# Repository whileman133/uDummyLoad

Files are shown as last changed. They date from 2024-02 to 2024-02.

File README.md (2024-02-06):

# 20W/50Ω μDummy RF Load with Wattmeter

This is the home of the design files and firmware for the μDummy RF Load project. See the description of the unit and the resources in this repo below.

## Description

This micro-size 50Ω RF dummy load with built-in wattmeter is well-suited for testing portable rigs. 
The glass LCD provides time-average power readings between 0.15 and 20W with 0.1W precision. 
Batteries are not required, as the unit draws power from the RF source, consuming a maximum of 3.0mA at the full rated input power. 
The board itself serves as a heatsink provided the operator limits the duration of the RF input. 
Improve the accuracy by loading a calibration table of up to 60 rows into EEPROM using an Arduino microcontroller.

## Organization of this Repo

- `2_Documentation/`: datasheet and documentation for the μDummy load unit
- `3_Mechanical/`: mechanical design files (primarily thermal analysis)
- `3_Electrical/`: KiCAD design files and LTspice simulation files
- `4_Software/`: firmware files
  - `uDummyLoad_PIC18F24Q10.X/`: firmware for the PIC microcontroller
  - `uDummyLoad_TranslatorArduino/`: Arduino sketch for uploading calibration table to the unit with an Arduino microcontroller

 ## License

Apache License, Version 2.0. See `LICENSE`.

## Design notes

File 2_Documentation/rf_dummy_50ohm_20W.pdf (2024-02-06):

## 20W/50Ω µDummy Load with Wattmeter

ASMV Electrical

Last Updated: February 6, 2024

Difficulty of Assembly: 3 out of 10 – Through-Hole Parts Only –

1

### Contents

2

RF-331: 20W Dummy Load | ASMV Electrical

### 1 Overview

This micro-size 50Ω RF dummy load with built-in wattmeter is well-suited for testing portable rigs. The glass LCD provides time-average power readings between 0.15 and 20W with 0.1W precision. Batteries are not required, as the unit draws power from the RF source, consuming a maximum of 3.0mA at the full rated input power. The board itself serves as a heatsink provided the operator limits the duration of the RF input. Improve the accuracy by loading a calibration table of up to 60 rows into EEPROM using an Arduino microcontroller.

Table 1: Characteristics

Parameter | Conditions Min. Typ. Max. Unit
Input power | 0.15¹

### 20 W

Peak ac input voltage | 3.9 | 45 | V
Wattmeter op. frequency | dc²

### 50 MHz

Dummy load op. frequency | dc | 150 | MHz
Uncalibrated error
(fin ≤ 10 MHz)
Pin = 1.0W | 0.1 | 0.2 | W
Pin = 20W | 0.7 | 1.3 | W
Uncalibrated error
(fin = 50 MHz)
Pin = 1.0W | 0.2 | 0.3 | W
Pin = 20W | 1.0 | 2.0 | W

Safe operating time
(TA = 25℃)
Pin = 10W | | 24 | sec
Pin = 15W | | 11 | sec
Pin = 20W | | 5 | sec
80% cool-down time³

### 3.5 min

3

RF-331: 20W Dummy Load | ASMV Electrical

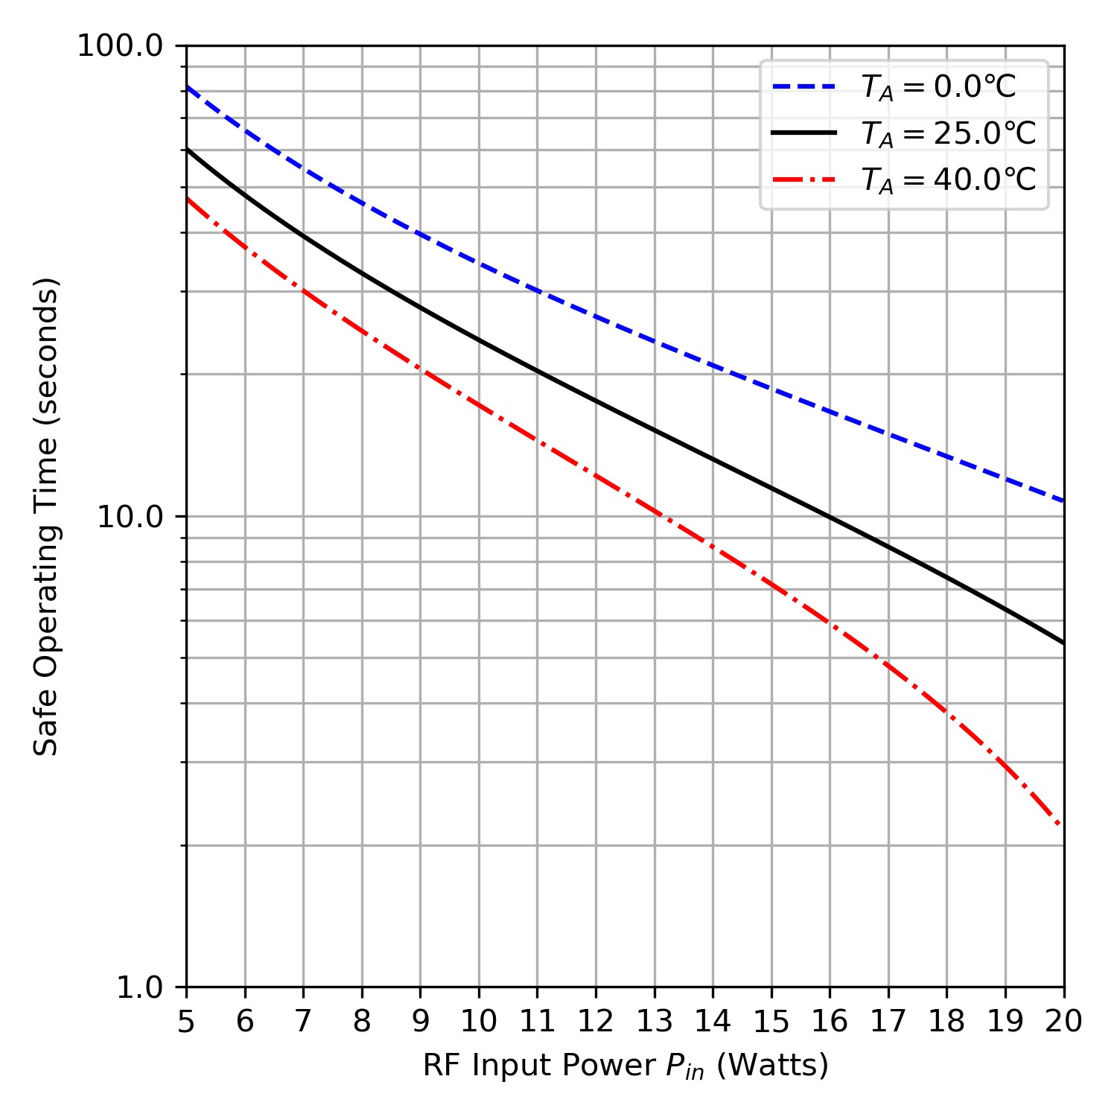
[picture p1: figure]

Figure 1: Safe Operating Time versus Input Power and Ambient Temperature

1The wattmeter will not operate when the input power falls below the rated minimum.
2To obtain the correct power at dc, double the meter reading.
3This is the cool-off time observed indoors with minimal air flow.

4

RF-331: 20W Dummy Load | ASMV Electrical

### 2 Assembly Instructions

Before proceeding, make sure that you have the parts in listed on this page and pictured on the next page. The board comes pre-populated with the surface-mount components. To complete the assembly, solder the remaining through-hole components to the board by following the steps on page 7. When complete, your board should look like the picture on on page 8. For best results, use rosin-core 63/37 PbSn solder, the eutectic alloy that melts at 181℃/361°F.

Parts List

Table 2: Kit Parts List

Qty. Reference(s) Description | Package Marking
1 | PCB | µDummy Load PCB | RF-331 Rev. 2
3 | D1, D2, D3 BAT46 Schottky diode | BAT46
2 | C1, C3 | 5.6nF peak-detector caps | 562
2 | C2, C4 | 1µF 100V decoupling caps | 105K
1 | C5 | 10nF decoupling cap | 103
1 | R3 | 100kΩ 0.1% precision resistor BrownBlackBlackOrangeViolet
1 | R4 | 10kΩ 0.1% precision resistor | BrownBlackBlackRedViolet
1 | R5 | 100kΩ 5% diode resistor | BrownBlackYellowGold
1 | R6 | 2.4kΩ 5%Vref resistor | RedYellowRedGold
1 | J1 | Male BNC 50Ω PCB-mount | —
1 | U4 | 24-pin reflective LCD | —

5

RF-331: 20W Dummy Load | ASMV Electrical

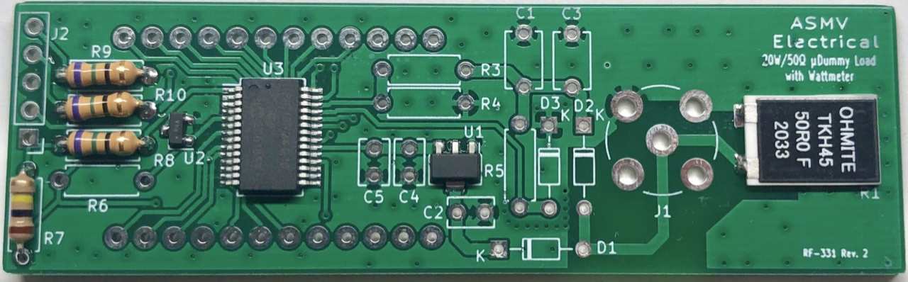
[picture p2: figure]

(a) PCB Front

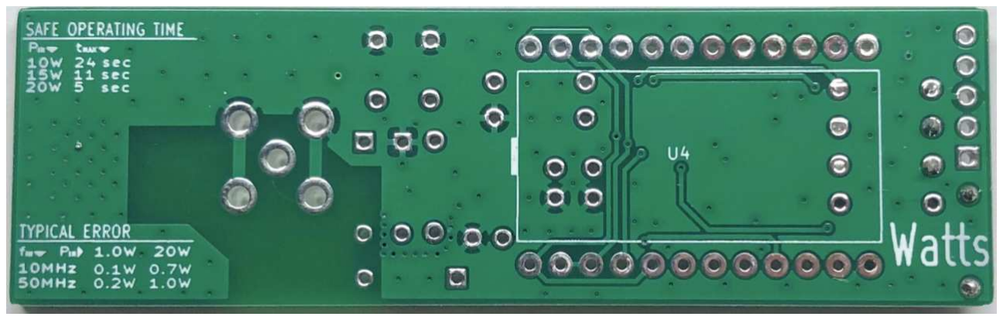
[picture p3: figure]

(b) PCB Back

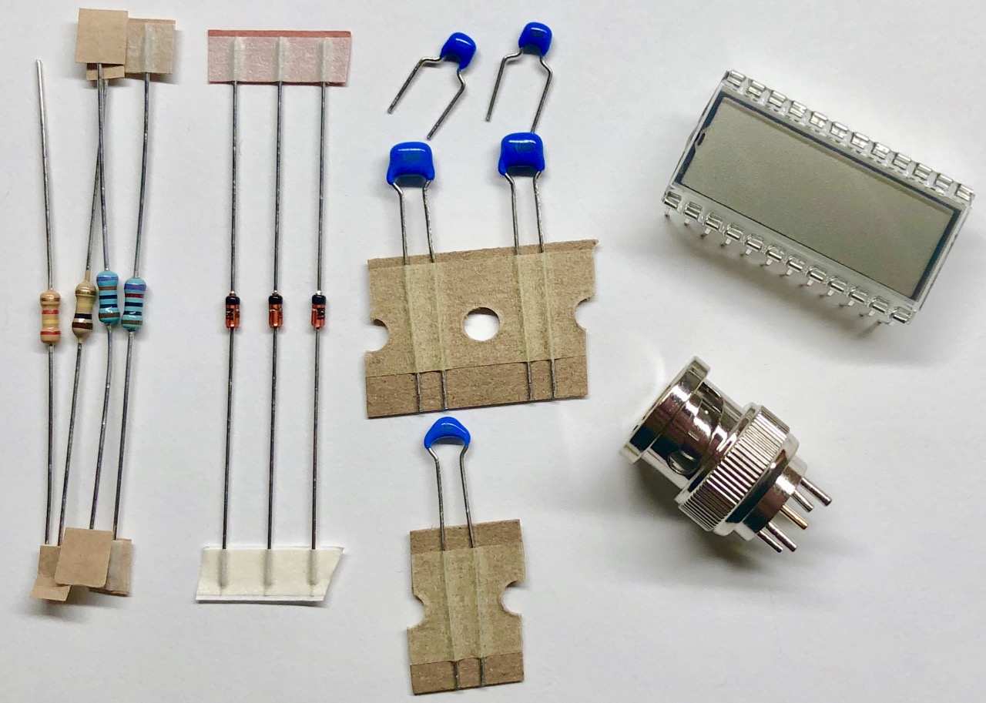
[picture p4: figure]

(c) Parts
Figure 2: Kit before assembly.

6

RF-331: 20W Dummy Load | ASMV Electrical

Assembly Steps

### 1. Place and solder the Schottky diodes D1, D2, D3 onto the board. Make

sure to orient the diodes so that the cathode band is closer to the pad marked “K”.

### 2. Place and solder the peak-detector capacitors C1, C3, the rectifier ca-

pacitor C2, and the diode biasing resistor R5 onto the board.

3. Place but do not solder the precision voltage divider resistors R3, R4, the decoupling capacitors C4, C5, and the voltage reference biasing resistor R6 onto the board.

### 4. Turn the board over and cut leads that protrude out of the LCD area

(U4) flush with the board. If necessary, remove the parts to cut the
leads. Rough or jagged pieces of metal extending out from the board may damage the LCD.
5. Solder the previously-placed parts R3, R4, C4, C5, R6 to the board.

### 6. Turn the board over and insert the 24-pin LCD (U4). Make sure to orient

the LCD so that the edge with the raised notch aligns with the mark on the silkscreen. Turn over the board and solder the LCD in place.

### 7. Place and solder the BNC connector J1 onto the board. Apply a rosin

flux to outer shield pins before soldering. These pins may require additional heat to form a good joint.

8. Remove the protective film from the LCD.

7

RF-331: 20W Dummy Load | ASMV Electrical

Assembled Board

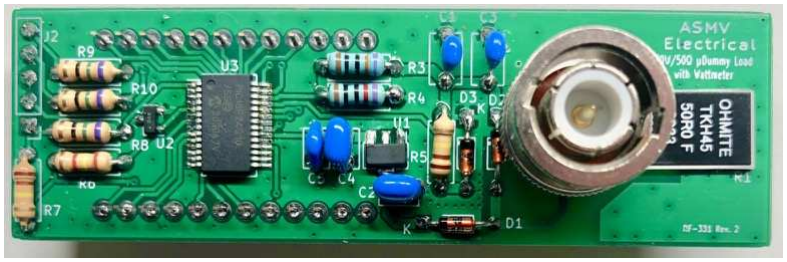
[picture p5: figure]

(a) Front

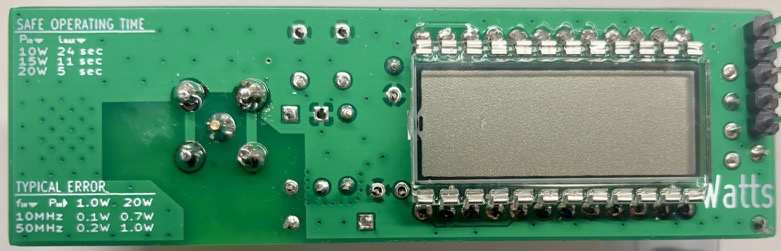
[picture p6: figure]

(b) Back
Figure 3: Assembled board.

8

RF-331: 20W Dummy Load | ASMV Electrical

### 3 Calibration Instructions

The µDummyLoad stores a calibration table and other configuration settings in the EEPROM of the on-board PIC microcontroller. The table consists of up to

### 60 rows mapping uncalibrated meter readings to corrected power values. The

µDummyLoad linearly interpolates between the provided calibration points. Program the EEPROM using an Arduino board (Uno, Nano, etc) and the provided configuration sketch by following the steps below.

1. Download the Arduino IDE (https://www.arduino.cc/en/software) and install it on a computer.

### 2. Download the uDummyLoadConfig configuration sketch and open it within

the Arduino IDE.

### 3. Follow the instructions in the configuration sketch to configure the µDummyLoad

to operate in calibration mode (to bypass any previously-loaded calibration table) and with extended 0.001W precision (to increase the calibration accuracy.)

### 4. Perform the calibration measurements by applying known power levels

and recording the meter readings. One way to do this is to insert a calibrated wattmeter in series with the feedline; another method is to measure the peak input voltage with a high-impedance oscilloscope and compute the input power as Pin = v

2
| pk/100; yet another is to use a rig
with a power output reading you trust.

### 5. Create a table mapping meter readings in milliwatts (first column) to the

known power readings in milliwatts (second column.) Sort the table
in ascending order by the column of meter readings. All values should be whole numbers of milliwatts.
6. Follow the instructions in the Arduino sketch to disable calibration mode, set precision back to 0.1W, and load the calibration table.

9

RF-331: 20W Dummy Load | ASMV Electrical

Table 3: Configuration Options

Name | Description | Default Range
precision | Selects the meter precision: Standard (STD): 0.1W Extended (EXT): 0.001W The display scans the last two mV digits in extended mode.
STD | STD/EXT
| | (1 bit)
enableCalibration | Enables calibration mode to bypass table
lookup so that new calibration readings can be taken.

false true/false
(1 bit)

enableDiodeComp Enables peak detector diode drop compensation by measuring the drop across a matched diode.

true true/false
(1 bit)

diodeOffsetMillivolt Offset to the measured peak voltage to account for the difference in the current flow between the compensation diode and the peak detector diode [millivolts].

### 17 mV 0–65,535

(16 bit)

displayPeriodMillisec Display update time period [milliseconds]. The display update routine requires at least 25ms to run.

100 ms 0–65,535
(16 bit)

samplePeriodMillisec A/D sampling time period [milliseconds]. The sampling routine requires at least 10ms to run.

50 ms | 0–255 (8 bit)
calibrationTable | Calibration table of up to 60 rows mapping the meter’s readings to corrected power values in milliwatts. The µDummyLoad linearly interpolates between the table rows.

Absent —

10

RF-331: 20W Dummy Load | ASMV Electrical

Table 4: µDummyLoad Error Codes

Error Code Description

01 Timeout waiting for master (Arduino) to release DAT/CLK lines.

02 Timeout waiting for master (Arduino) to send data.

03 Receive buffer overflowed 255 bytes.

04 Data header missing or malformed.

05 Calibration table malformed.

06 Calibration table not sorted in ascending order.

11

RF-331: 20W Dummy Load | ASMV Electrical

### 4 Detailed Description

The block diagram of Figure 4 shows the functional units of the dummy-load module—primarily, a 50Ω load resistor, a PIC18 microcontroller, and a three-digit liquid crystal display (LCD). The radio-frequency (RF) input powers the PIC18 and LCD via a rectifier followed by linear regulator. The complete electrical schematic appears in Figure 5.

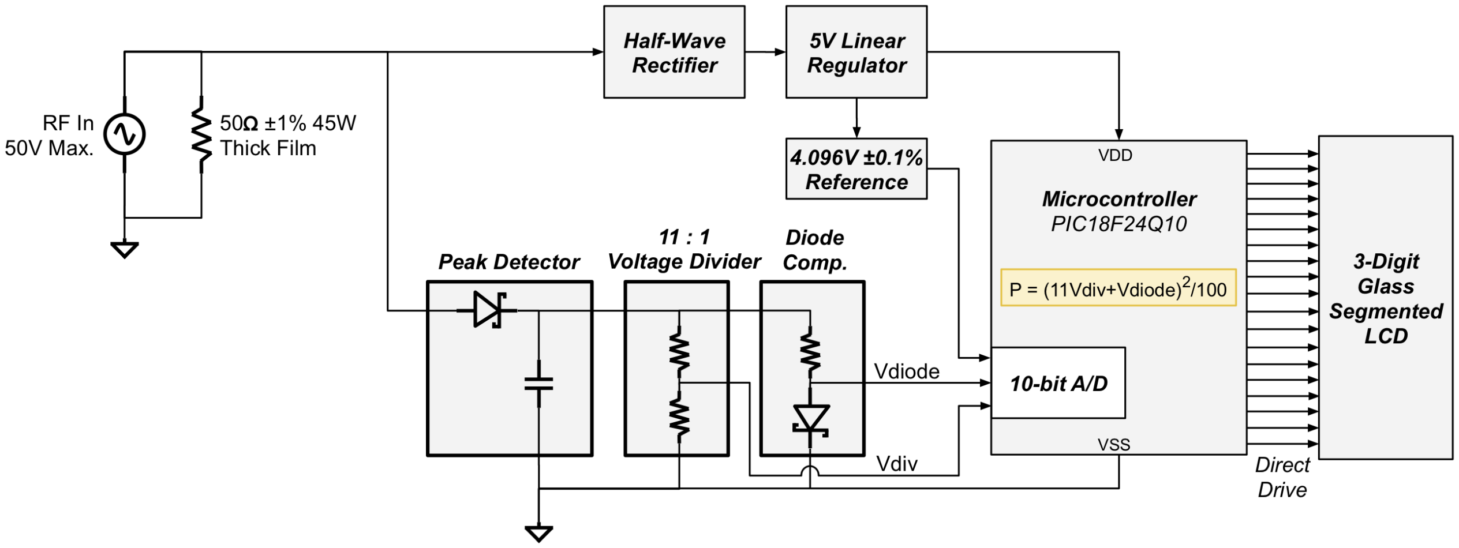
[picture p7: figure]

Figure 4: Block Diagram

The circuit detects the RF envelope voltage with a Schottky-diode peak detector. A 10-bit SAR A/D converter within the microcontroller samples the divided envelope voltage and the voltage across a matched diode to compensate for the diode drop of the peak detector. The PIC18 then computes the average power absorbed by the load resistor as

P =

(AdivVdiv + VF )

2

2Rload
where Adiv = 11V/V is the division factor of the voltage divider, Rload = 50Ω is the load resistance, Vdiv is the voltage measured at the voltage divider output, and VF is the forward voltage drop across the detector diode computed from the

12

RF-331: 20W Dummy Load | ASMV Electrical

voltage measured across the compensation diode Vdiode. In the Peak Detector section, it is shown that VF ≈ Vdiode + 17mV.
From the 10-bit digital code Cdiv liberated by the A/D converter, the voltage divider output voltage is

Vdiv =

Cdiv
1023

Vref

where Vref = 4.096V is the external 0.1% precision Zener voltage reference. In the following sections, we’ll denote the units of Cdiv with least-significant bits (LSb).

Load Resistor

A 50Ω/45W thick-film resistor dissipates the input RF power Pin. This resistor is housed in a surface-mount package with heatsink pad in contact with the top and bottom ground pours on the circuit board. The board itself serves as the heatsink and its heat capacity limits the maximum time the load is able to withstand input power without damaging the resistive element. See the Thermal Considerations Section for details.
Manufacturing variation of the load resistance introduces error in the power reading. The nominal load resistance is Rload = 50Ω with a tolerance of t = 1% and temperature coefficient of α = 100ppm/℃. Over the industrial temperature range, the maximum error in the load resistance is then ∆Rload = (t/100)Rload+(α/10⁶
)Rload×65℃, which comes out to ∆Rload = 0.825Ω. The maximum error in the power reading is

∆Perr ≈ Pin

∆Rload

Rload
The error is 0.017W when Pin = 1.0W and 0.33W when Pin = 20.0W.
At frequencies above 50MHz, the load impedance deviates significantly from 50Ω due to parasitic inductance and capacitance of the thick-film resistor

13

RF-331: 20W Dummy Load | ASMV Electrical

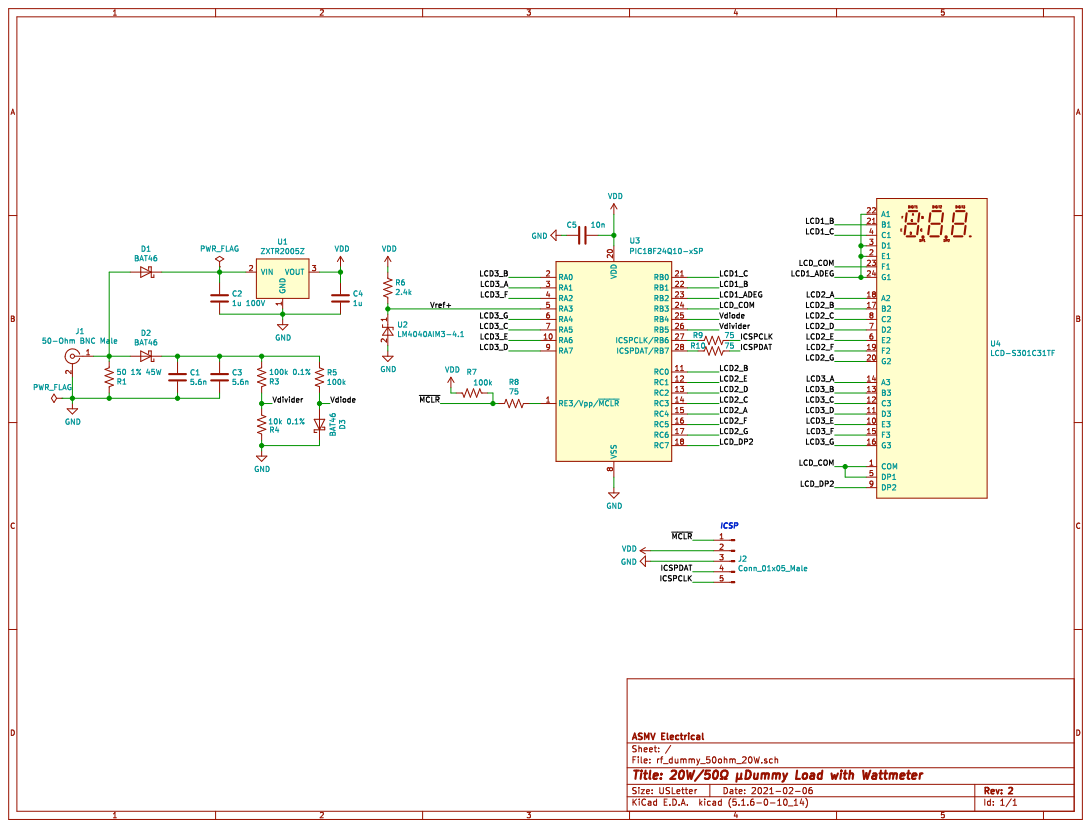
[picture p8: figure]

Figure 5: Electrical Schematic

and the circuit-board traces. A lumped-element model of the resistor, resistor case parasitics, and circuit-board trace parasitics appears in Figure 6. Figure 7 is a computer-generated plot of the resistor’s impedance ZR and the impedance Z seen at the input to the μDummy load. At an input frequency of 10MHz, the impedance differs from 50Ω by 0.075Ω. The resulting error in the power reading is 0.0015W when Pin = 1.0W and 0.03W when Pin = 20.0W. At 50MHz the difference is 1.88Ω; the error is 0.038W when Pin = 1.0W and

14

RF-331: 20W Dummy Load | ASMV Electrical

0.75W when Pin = 20.0W.

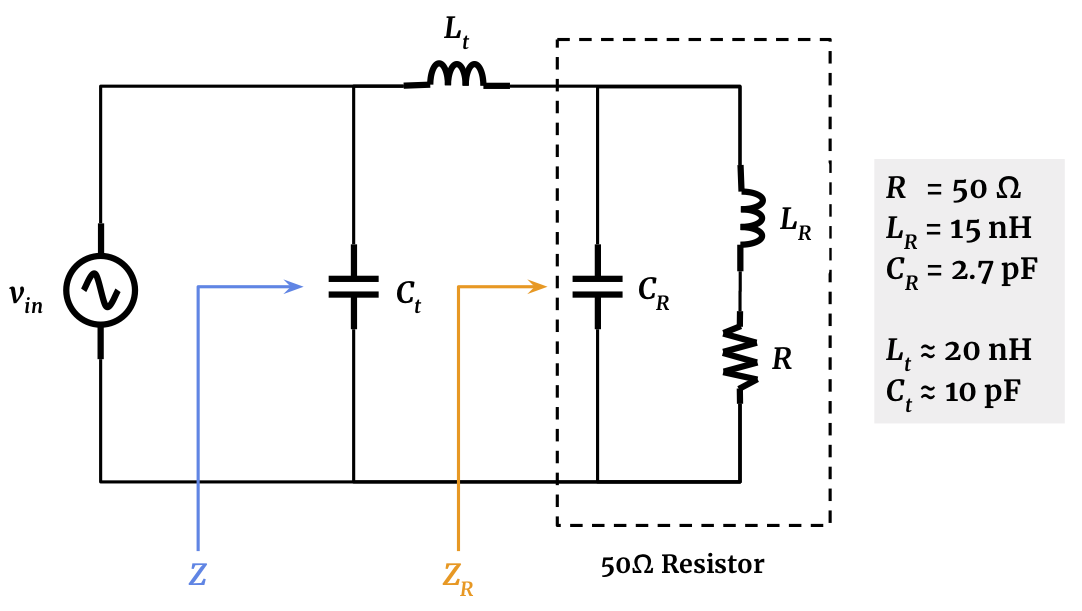
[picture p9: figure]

Figure 6: Equivalent Load Circuit

15

RF-331: 20W Dummy Load | ASMV Electrical

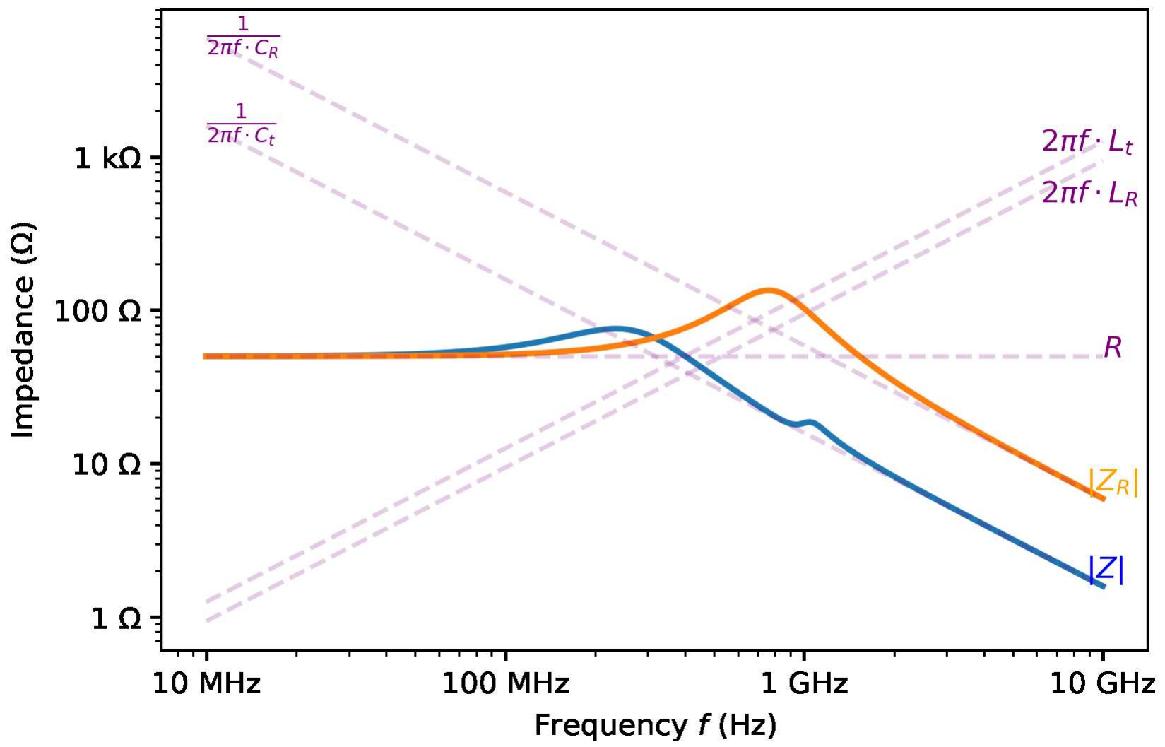
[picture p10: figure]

Figure 7: Load Impedance vs. Frequency

Peak Detector

The unit employs a BAT46 Schottky diode and two parallel-connected 5.6nF capacitors to detect the envelope of the RF input voltage. Positive half-cycles of the input forward bias the diode and charge the capacitors to the peak input voltage Vpk; in negative half-cycles, the diode is reverse biased with a maximum reverse voltage of max(VR) = 2Vpk. Reverse breakdown occurs at 100V for BAT46, limiting the peak input voltage to 50V and the input power to V

2

pk/2Rload = 50²
/100 = 25W.

16

RF-331: 20W Dummy Load | ASMV Electrical

The voltage divider loads the peak detector, somewhat reducing its accuracy. The total resistance of the divider is Rdiv = 110kΩ, drawing a current of approximately Idiv = Vpk/Rdiv or about 450μA at 50V envelope voltage. The diode must conduct this current in positive half-cycles to charge the capacitors, resulting in a forward voltage drop VF across the diode near 0.3V. The error in the power reading due to to an error in the measured peak voltage of ∆Verr is

∆Perr ≈ ∆Verr ·

r
2Pin

Rload

| (1)

where Pin is the input power and Rload = 50Ω is the load resistance. Setting ∆Verr = VF , the error due to the diode drop is about 0.06W for Pin = 1.0W; for Pin = 20W, it is about 0.27W.
The μDummy load measures the voltage across a dc-biased BAT46 diode to partially compensate the drop in the peak detector. A diode from the same production lot as the detector diode is forward biased by the envelope voltage and a 100kΩ resistor. The PIC18 samples the forward voltage across this compensation diode VF(comp) and, from this measurement, computes the forward voltage drop across the detector diode VF as follows. When forward voltage exceeds several tens of millivolts, the detector and compensation diode currents are

I ≈ Ise

V /ηVT

Icomp ≈ Ise

VF (comp)/ηVT

where Is is a diode parameter called the saturation current, VT is the thermal voltage equal to 0.0259V at room temperature, and η is the diode ideality factor near 1.0 for Schottky diodes. Dividing the first equation by the second and solving for VF results in the formula

17

RF-331: 20W Dummy Load | ASMV Electrical

VF = VF(comp) + VT ln
I

Icomp

The saturation current Is cancels out since the diodes are matched. This equation can be further reduced by noting the compensation diode current is Icomp ≈ Vpk/Rcomp,where Rcomp = 100kΩ is the biasing resistance and the average detector diode current is I ≈ Vpk/(Rdiv||Rcomp) where Rdiv = 110kΩ is the voltage divider resistance:

VF = VF(comp) + VT ln
1 +

Rcomp

Rdiv

At room temperature, VF = VF(comp) + 0.017V; the detector diode voltage equals the compensator diode voltage plus about 17mV. The change in the 17mV offset is less than ±4.0mV over the -40℃ to +85℃ industrial temperature range and is neglected in this application due to lack of a calibrated temperature sensor. The PIC18 contains an internal temperature sensor that could be manually calibrated for this application, though this will do little to improve the overall compensation accuracy.
This method of compensation still results in error due to diode mismatch and differences in the conduction methods. The compensation diode is dc-biased, while the current through the detector diode flows in pulses, remaining near zero except at peaks of the RF input, during which the instantaneous detector current i(t) will exceed the averaged current I used in the above equations. This causes the detector diode’s forward voltage drop to exceed the figures predicted by the foregoing equations. Suppose the error in VF is limited to about 0.1V maximum. The resulting error in the power reading is then 0.09W when the input power is 20W and 0.02W when the input power is 1W.

18

RF-331: 20W Dummy Load | ASMV Electrical

Microcontroller and Display

A surface-mount package houses the PIC18 to reduce board area and routing complexity. This PIC18 is powered from a 5V linear regulator and is clocked by an internal 1MHz oscillator (HFINTOSC).
Power readings are output to a three-digit transflective LCD where the digits are 7-segmented. To “activate” a segment of a particular digit, the PIC18 alternates the voltage applied to that segment between +5V and -5V at a rate of 30Hz; to disable a segment, the PIC18 drives the segment voltage to zero. One side of the LCD segments contact a common line labeled “COM” and separate lines expose the other sides of the segments. There are a total of 24 lines on the display (COM line, 21 segment lines, and 2 decimal point lines), but the PIC18 has enough outputs to drive only two complete digits. The meter need only read up to 20.0W, and thus the first digit is wired to display the numbers “1” and “2” only, reducing the pin count.
When driving the LCD and performing periodic A/D conversions, the PIC18 draws about 800μA from the linear regulator. The external voltage reference draws an additional 600μA from the regulator, and the quiescent current of the linear regulator is about 600μA. The combined power draw of the PIC18 and voltage reference from the RF input is then (800+600+600)µA·Vpk. Add to this the power dissipated by the envelope voltage divider and compensation diode V

2
pk/(Rdiv||Rcomp) and the total parasitic power draw is

Pparasitic = (2.0 + Vpk/52.4)mA · Vpk With Vpk = 45V (Pin ≈ 20.0W), Pparasitic = 0.148W; with Vpk = 10V (Pin ≈ 1.0W), Pparasitic = 0.022W. This parasitic power draw constitutes error in the power reading.

19

RF-331: 20W Dummy Load | ASMV Electrical

Additional Sources of Error

Aside from the diode drop of the peak detector, the parasitic power draw of the PIC18, and load resistance error discussed previously, several other factors contribute to error in the power reading. These include absolute error of the A/D converter, voltage reference drift, and error in the voltage divider resistances.

A/D Converter Error From the Electrical Specifications section of the PIC18 data-sheet⁴
, the worst-case integral nonlinearity is 1.0 LSb, worst-case offset error is 2.0 LSb, and worst-case gain error is 2.0 LSb. The maximum error is the sum of these contributions, 5.0 LSb. With a nominal reference voltage of Vref = 4.096V and voltage division factor of Adiv = 11V/V, the worst-case error in the peak voltage reading is ∆Verr = 11 × 4.096V × (5LSb/1023) = 0.22V. The corresponding error in the power reading given by Equation (1): 0.04W at Pin = 1.0W and 0.2W at Pin = 20.0W.

Voltage Reference Error The LM4040 4.096V zener reference has an output voltage error of ∆Vref = ±0.031V over the full industrial operating temperature range⁵
. The resulting worst-case error in the peak voltage reading is ∆Verr = Adiv∆Vref = 0.341V, and error in the power reading is 0.07W at Pin = 1.0W and 0.3W at Pin = 20.0W. The error is lower when operating within a narrower temperature range. For example, within the 10℃ to 40℃ temperature range, ∆Vref = ±0.0164V, giving a power error of 0.036W at Pin = 1.0W and 0.16W at Pin = 20.0W.

Voltage-Divider Resistance Error The division factor of the peak detector voltage-divider is Adiv = 1 + Rtop/Rbot where Rtop = 100kΩ (nominal) is the value of the upper resistor and Rbot = 10kΩ (nominal) is the value of the

4The PIC18 datasheet is available for download on Microchip’s website via this link. (http://ww1.microchip.com/downloads/en/DeviceDoc/PIC18F2425Q10-28-Pin-Low-Power-High-Performance-MCU-40001945C.pdf)
5The LM4040 datasheet is available for download on Texas Instrument’s website via this link. (https://www.ti.com/lit/ds/symlink/lm4040-n.pdf)

20

RF-331: 20W Dummy Load | ASMV Electrical

lower resistor. The error in the voltage division factor Adiv due to deviation of the resistance values from nominal, ∆Rtop and ∆Rbot, is given by the total differential approximation

∆Adiv ≈

1

Rbot

∆Rtop −

Rtop
R²
bot

∆Rbot

The maximum error occurs when ∆Rtop and ∆Rbot have different signs (i.e. when the upper resistance is higher than nominal and the lower resistance is lower than nominal, or vise versa) and is given by

max |∆Adiv| ≈ 1

Rbot

|∆Rtop| +

Rtop
R²
bot

|∆Rbot|

Writing the resistance errors in terms of the resistor percent tolerance t as |∆Rtop| = (t/100)Rtop and |∆Rbot| = (t/100)Rbot results in the formula

max |∆Adiv| ≈ 2t
100

Rtop

Rbot

=

2t
100

(Adiv − 1)

With a nominal division factor of Adiv = 11V/V and resistor tolerance of t = 0.1%, the maximum error in the division factor is 0.02V/V. The corresponding maximum error in the power reading is

∆Perr ≈ 2Pin

max |∆Adiv|

Adiv
The error is 0.004W for Pin = 1.0W and 0.073W for Pin = 20.0W.

Thermal Considerations

A simplified thermal model of the μDummy load appears in Figure 8. The thermal model is similar to an electrical circuit where power (heat flow) replaces current, temperature replaces voltage, thermal resistance replaces elecrical reistance, and heat capacity replaces capacitance.

21

RF-331: 20W Dummy Load | ASMV Electrical

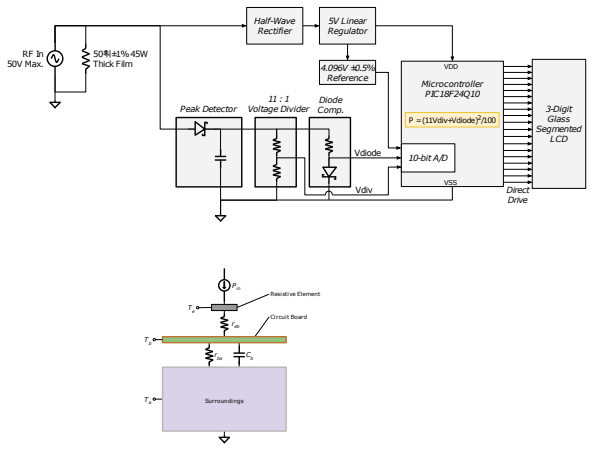
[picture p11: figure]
Direct Drive; Half-Wave Rectifier; 5V Linear Regulator; 4.096V ±0.5% Reference; 3-Digit Glass Segmented LCD; Peak Detector; 11 : 1 Voltage Divider; VDD; VSS; 10-bit A/D; Microcontroller PIC18F24Q10; P = (11Vdiv+Vdiode)² /100; 50흮±1% 45W Thick Film; RF In 50V Max.; Diode Comp.; Vdiv; Vdiode; Pin; reb; rba; Circuit Board; Resistive Element; Surroundings

Figure 8: Thermal Diagram

In the model, Te is the temperature of the resistive element, Tb

is the
temperature of the board (assumed isothermal for simplicity), and Ta is the temperature of the surroundings. The thermal resistance reb is a measure of the opposition that the resistor’s casing presents to heat flow from the internal resistive element to the heatsink pad—i.e from the element (e) and the board (b). For the Ohmite part used in this application, reb = 3℃/W. Similarly, rba is the heat resistance between the board and the surroundings. Its value depends on the size of the board, air flow rate, and other factors. Last, Cb

is
the heat capacity of the board and may be approximated as

Cb ≈ mCucCu + mF R4cF R4
where mCu is the total mass of copper on the board, cCu is the specific heat capacity of copper, mF R4 is the mass of FR-4 dielectric in the board’s interior, and cF R4 is the specific heat capacity of FR-4. Substituting the appropriate values, we find Cb ≈ 4.3J/℃ for the μDummy load board.
Assuming rba >> reb such that rba may be neglected, the initial temperature of the board is equal to the ambient Tb(0) = Ta, and that constant RF power Pin is applied starting at time t = 0, the solution for Te is

22

RF-331: 20W Dummy Load | ASMV Electrical

Te(t) ≈

Pin
Cb

t + Pinreb + Ta

The temperature of the resistive element increases linearly with time, eventually growing large enough to damage the resistor if the input RF power is not removed. According to the power derating curve in the resistor’s data-sheet, to safely dissipate the full rated power of 20W, the element must be held below about Te(max) = 110℃. The time at which Te reaches Te(max)

is

tmax = Cb

Te(max) − Ta

Pin

− reb

A plot of tmax versus the input power appears in the Overview Section at several ambient temperature values. The safe operating time predicted by this formula is somewhat pessimistic since we neglect heat lost to convection and radation from the board to the ambient.
After we remove the input power, the temperature of the board decays exponentially to ambient with the termal time constant

τ = rbaCb
which is the time required for the board temperature to decay to 37% of its initial value above ambient. Based on empirical observation, the board-toambient thermal resistance rba is approximately 30℃/W (indoors with minimal air flow). The time constant is then τ = (30)(4.3) = 129 sec. The 80% cool-down time (the time required for the board to reach 20% of its initial value above ambient) is 1.6τ = 206 sec, or about 3.5 minutes.

23

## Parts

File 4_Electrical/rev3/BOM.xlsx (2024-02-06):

Qty | Reference(s) | Value | Description | Man | Vendor | VendorPN | Quantity | Unit Price (1 assy) | Ext. Price (1 assy)
2 | C1, C3 | 5.6n | CAP CER 5600PF 100V C0G RADIAL |  | DigiKey | 445-181255-ND | 2 | $0.41 | $0.82
1 | C2, C4 | 1u 100V | CAP CER 1UF 100V X7R RADIAL | TDK Corporation | DigiKey | 445-173162-1-ND | 2 | $0.73 | $1.46
1 | C5 | 10n | CAP CER 10000PF 50V X7R RADIAL | TDK Corporation | DigiKey | 445-173264-1-ND | 1 | $0.28 | $0.28
3 | D1, D2, D3 | BAT46 | DIODE SCHOTTKY 100V 150MA DO35 | Vishay | DigiKey | BAT46CT-ND | 3 | $0.46 | $1.38
1 | J1 | 50-Ohm BNC Male | CONN BNC JACK STR 50 OHM PCB | TE Connectivity AMP Connectors | DigiKey | A97581-ND | 1 | $2.35 | $2.35
1 | R1 | 50 1% 45W | RES 50 OHM 1% 45W TO252 | Ohmite | DigiKey | TKH45P50R0FECT-ND | 1 | $2.52 | $2.52
1 | R3 | 100k 0.1% | RES 100K OHM 1/4W .1% AXIAL | Stackpole Electronics | DigiKey | RNF14BTE100KCT-ND | 1 | $0.60 | $0.60
1 | R4 | 10k 0.1% | RES 10K OHM 1/4W .1% AXIAL | Stackpole Electronics | DigiKey | RNF14BTE10K0CT-ND | 1 | $0.60 | $0.60
2 | R5, R7 | 100k | RES 100K OHM 1/4W 1% AXIAL | Yageo | DigiKey | 100KXBK-ND | 2 | $0.10 | $0.20
1 | R6 | 2.4k | RES 2.4K OHM 1/4W 5% AXIAL | Yageo | DigiKey | 2.4KQBK-ND | 1 | $0.10 | $0.10
3 | R8, R9, R10 | 75 | RES 75 OHM 1/4W 5% AXIAL | Yageo | DigiKey | 75QBK-ND | 3 | $0.10 | $0.30
1 | U1 | ZXTR2005Z | IC REG LINEAR 5V 38MA SOT89 | Diodes Incorporated | DigiKey | ZXTR2005Z-13DICT-ND | 1 | $0.56 | $0.56
1 | U2 | LM4040AIM3-4.1 | IC VREF SHUNT 0.1% SOT23-3 | Microchip Technology | DigiKey | LM4040AIM3-4.1/NOPBCT-ND | 1 | $1.89 | $1.89
1 | U3 | PIC18F24Q10-xSP | IC MCU 8BIT 16KB FLASH 28SSOP | Microchip Technology | DigiKey | PIC18F24Q10-I/SS-ND | 1 | $0.99 | $0.99
1 | U4 | LCD-S301C31TF | LCD MOD 3DIG 3 X 1 TRANSFLECTIVE | Lumex Opto/Components Inc. | DigiKey | 67-1799-ND | 1 | $2.57 | $2.57
 |  |  |  |  |  |  |  | 1 assy > | $16.62
 |  |  |  |  |  |  |  | 10 assy > | $13.42 | ea
 |  |  |  |  |  |  |  | 30 assy > | $12.36 | ea
 |  |  |  |  |  |  |  | 60 assy > | $11.40 | ea
 |  |  |  |  |  |  |  | 100 assy > | $9.84 | ea
 |  |  |  |  |  |  |  | 250 assy > | $9.01 | ea
 |  |  |  |  |  |  |  | 500 assy > | $7.74 | ea
 |  |  |  |  |  |  |  | 1000 assy > | $7.05 | ea
 |  |  |  |  |  |  |  | 2000 assy > | $7.00 | ea

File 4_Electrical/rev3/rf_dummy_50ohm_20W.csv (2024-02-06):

Source: | /Users/Wes/Desktop/rf_dummy_50ohm_20W/4_Electrical/rev3/rf_dummy_50ohm_20W.sch
Date: | Wednesday, March 31, 2021 at 10:03:57 AM
Tool: | Eeschema (5.1.6-0-10_14)
Generator: | /Applications/KiCad/kicad.app/Contents/SharedSupport/plugins/bom_csv_grouped_by_value.py
Component Count: | 23
Individual Components:
Item | Qty | Reference(s) | Value | LibPart | Footprint | Datasheet | Man | Vendor | VendorPN
 |  | C1 | 5.6n | Device:C | Capacitor_THT:C_Disc_D5.1mm_W3.2mm_P5.00mm | https://product.tdk.com/info/en/documents/chara_sheet/FG24C0G2A562JNT00.pdf |  | DigiKey | 445-181255-ND
 |  | C2 | 1u 100V | Device:C | Capacitor_THT:C_Rect_L4.0mm_W2.5mm_P2.50mm | ~ | TDK Corporation | DigiKey | 445-173162-1-ND
 |  | C3 | 5.6n | Device:C | Capacitor_THT:C_Disc_D5.1mm_W3.2mm_P5.00mm | https://product.tdk.com/info/en/documents/chara_sheet/FG24C0G2A562JNT00.pdf |  | DigiKey | 445-181255-ND
 |  | C4 | 1u | Device:C | Capacitor_THT:C_Rect_L4.0mm_W2.5mm_P2.50mm | ~ | TDK Corporation | DigiKey | 445-173162-1-ND
 |  | C5 | 10n | Device:C | Capacitor_THT:C_Rect_L4.0mm_W2.5mm_P2.50mm | ~ | TDK Corporation | DigiKey | 445-173264-1-ND
 |  | D1 | BAT46 | Device:D_Schottky | Diode_THT:D_DO-34_SOD68_P7.62mm_Horizontal | https://www.vishay.com/docs/85662/bat46.pdf | Vishay | DigiKey | BAT46CT-ND
 |  | D2 | BAT46 | Device:D_Schottky | Diode_THT:D_DO-34_SOD68_P7.62mm_Horizontal | https://www.vishay.com/docs/85662/bat46.pdf | Vishay | DigiKey | BAT46CT-ND
 |  | D3 | BAT46 | Device:D_Schottky | Diode_THT:D_DO-34_SOD68_P7.62mm_Horizontal | https://www.vishay.com/docs/85662/bat46.pdf | Vishay | DigiKey | BAT46CT-ND
 |  | J1 | 50-Ohm BNC Male | Connector:Conn_Coaxial | WH_Connector_Coaxial:BNC_TEConnectivity_1478204_Vertical | https://www.te.com/commerce/DocumentDelivery/DDEController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 | TE Connectivity AMP Connectors | DigiKey | A97581-ND
 |  | J2 | Conn_01x05_Male | Connector:Conn_01x05_Male | Connector_PinHeader_2.54mm:PinHeader_1x05_P2.54mm_Vertical | ~ | Adam Tech | DigiKey | 2057-PH1RA-05-UA-ND
 |  | R1 | 50 1% 45W | Device:R_US | Package_TO_SOT_SMD:TO-252-2_TabPin1 | https://www.ohmite.com/assets/docs/res_tkh.pdf?r=false | Ohmite | DigiKey | TKH45P50R0FECT-ND
 |  | R3 | 100k 0.1% | Device:R_US | Resistor_THT:R_Axial_DIN0207_L6.3mm_D2.5mm_P7.62mm_Horizontal | ~ | Stackpole Electronics | DigiKey | RNF14BTE100KCT-ND
 |  | R4 | 10k 0.1% | Device:R_US | Resistor_THT:R_Axial_DIN0207_L6.3mm_D2.5mm_P7.62mm_Horizontal | ~ | Stackpole Electronics | DigiKey | RNF14BTE10K0CT-ND
 |  | R5 | 100k | Device:R_US | Resistor_THT:R_Axial_DIN0207_L6.3mm_D2.5mm_P7.62mm_Horizontal | ~ | Yageo | DigiKey | 100KXBK-ND
 |  | R6 | 2.4k | Device:R_US | Resistor_THT:R_Axial_DIN0207_L6.3mm_D2.5mm_P7.62mm_Horizontal | ~ | Yageo | DigiKey | 2.4KQBK-ND
 |  | R7 | 100k | Device:R_US | Resistor_THT:R_Axial_DIN0207_L6.3mm_D2.5mm_P7.62mm_Horizontal | ~ | Yageo | DigiKey | 100KXBK-ND
 |  | R8 | 75 | Device:R_US | Resistor_THT:R_Axial_DIN0207_L6.3mm_D2.5mm_P7.62mm_Horizontal | ~ | Yageo | DigiKey | 75QBK-ND
 |  | R9 | 75 | Device:R_US | Resistor_THT:R_Axial_DIN0207_L6.3mm_D2.5mm_P7.62mm_Horizontal | ~ | Yageo | DigiKey | 75QBK-ND
 |  | R10 | 75 | Device:R_US | Resistor_THT:R_Axial_DIN0207_L6.3mm_D2.5mm_P7.62mm_Horizontal | ~ | Yageo | DigiKey | 75QBK-ND
 |  | U1 | ZXTR2005Z | WH_Regulator_Linear:ZXTR2005Z | Package_TO_SOT_SMD:SOT-89-3 | https://www.diodes.com/assets/Datasheets/ZXTR2005Z.pdf | Diodes Incorporated | DigiKey | ZXTR2005Z-13DICT-ND
 |  | U2 | LM4040AIM3-4.1 | Reference_Voltage:LM4040DBZ-4.1 | Package_TO_SOT_SMD:SOT-23 | http://www.ti.com/lit/ds/symlink/lm4040-n.pdf | Microchip Technology | DigiKey | LM4040AIM3-4.1/NOPBCT-ND
 |  | U3 | PIC18F24Q10-xSP | frebourg_MCU_Microchip_PIC18:PIC18F24Q10-xSS | Package_SO:SSOP-28_5.3x10.2mm_P0.65mm | http://ww1.microchip.com/downloads/en/DeviceDoc/PIC18F2425Q10-28-Pin-Low-Power-High-Performance-MCU-40001945C.pdf | Microchip Technology | DigiKey | PIC18F24Q10-I/SS-ND
 |  | U4 | LCD-S301C31TF | WH_Display_Character:LCD-S301C31TF | WH_Display_Character:LCD-S301C31TF | https://www.lumex.com/datasheet/LCD-S301C31TF | Lumex Opto/Components Inc. | DigiKey | 67-1799-ND
Collated Components:
Item | Qty | Reference(s) | Value | LibPart | Footprint | Datasheet | Man | Vendor | VendorPN
1 | 2 | C1, C3 | 5.6n | Device:C | Capacitor_THT:C_Disc_D5.1mm_W3.2mm_P5.00mm | https://product.tdk.com/info/en/documents/chara_sheet/FG24C0G2A562JNT00.pdf |  | DigiKey | 445-181255-ND
2 | 1 | C2 | 1u 100V | Device:C | Capacitor_THT:C_Rect_L4.0mm_W2.5mm_P2.50mm | ~ | TDK Corporation | DigiKey | 445-173162-1-ND
3 | 1 | C4 | 1u | Device:C | Capacitor_THT:C_Rect_L4.0mm_W2.5mm_P2.50mm | ~ | TDK Corporation | DigiKey | 445-173162-1-ND
4 | 1 | C5 | 10n | Device:C | Capacitor_THT:C_Rect_L4.0mm_W2.5mm_P2.50mm | ~ | TDK Corporation | DigiKey | 445-173264-1-ND
5 | 3 | D1, D2, D3 | BAT46 | Device:D_Schottky | Diode_THT:D_DO-34_SOD68_P7.62mm_Horizontal | https://www.vishay.com/docs/85662/bat46.pdf | Vishay | DigiKey | BAT46CT-ND
6 | 1 | J1 | 50-Ohm BNC Male | Connector:Conn_Coaxial | WH_Connector_Coaxial:BNC_TEConnectivity_1478204_Vertical | https://www.te.com/commerce/DocumentDelivery/DDEController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 | TE Connectivity AMP Connectors | DigiKey | A97581-ND
7 | 1 | J2 | Conn_01x05_Male | Connector:Conn_01x05_Male | Connector_PinHeader_2.54mm:PinHeader_1x05_P2.54mm_Vertical | ~ | Adam Tech | DigiKey | 2057-PH1RA-05-UA-ND
8 | 1 | R1 | 50 1% 45W | Device:R_US | Package_TO_SOT_SMD:TO-252-2_TabPin1 | https://www.ohmite.com/assets/docs/res_tkh.pdf?r=false | Ohmite | DigiKey | TKH45P50R0FECT-ND
9 | 1 | R3 | 100k 0.1% | Device:R_US | Resistor_THT:R_Axial_DIN0207_L6.3mm_D2.5mm_P7.62mm_Horizontal | ~ | Stackpole Electronics | DigiKey | RNF14BTE100KCT-ND
10 | 1 | R4 | 10k 0.1% | Device:R_US | Resistor_THT:R_Axial_DIN0207_L6.3mm_D2.5mm_P7.62mm_Horizontal | ~ | Stackpole Electronics | DigiKey | RNF14BTE10K0CT-ND
11 | 2 | R5, R7 | 100k | Device:R_US | Resistor_THT:R_Axial_DIN0207_L6.3mm_D2.5mm_P7.62mm_Horizontal | ~ | Yageo | DigiKey | 100KXBK-ND
12 | 1 | R6 | 2.4k | Device:R_US | Resistor_THT:R_Axial_DIN0207_L6.3mm_D2.5mm_P7.62mm_Horizontal | ~ | Yageo | DigiKey | 2.4KQBK-ND
13 | 3 | R8, R9, R10 | 75 | Device:R_US | Resistor_THT:R_Axial_DIN0207_L6.3mm_D2.5mm_P7.62mm_Horizontal | ~ | Yageo | DigiKey | 75QBK-ND
14 | 1 | U1 | ZXTR2005Z | WH_Regulator_Linear:ZXTR2005Z | Package_TO_SOT_SMD:SOT-89-3 | https://www.diodes.com/assets/Datasheets/ZXTR2005Z.pdf | Diodes Incorporated | DigiKey | ZXTR2005Z-13DICT-ND
15 | 1 | U2 | LM4040AIM3-4.1 | Reference_Voltage:LM4040DBZ-4.1 | Package_TO_SOT_SMD:SOT-23 | http://www.ti.com/lit/ds/symlink/lm4040-n.pdf | Microchip Technology | DigiKey | LM4040AIM3-4.1/NOPBCT-ND
16 | 1 | U3 | PIC18F24Q10-xSP | frebourg_MCU_Microchip_PIC18:PIC18F24Q10-xSS | Package_SO:SSOP-28_5.3x10.2mm_P0.65mm | http://ww1.microchip.com/downloads/en/DeviceDoc/PIC18F2425Q10-28-Pin-Low-Power-High-Performance-MCU-40001945C.pdf | Microchip Technology | DigiKey | PIC18F24Q10-I/SS-ND
17 | 1 | U4 | LCD-S301C31TF | WH_Display_Character:LCD-S301C31TF | WH_Display_Character:LCD-S301C31TF | https://www.lumex.com/datasheet/LCD-S301C31TF | Lumex Opto/Components Inc. | DigiKey | 67-1799-ND

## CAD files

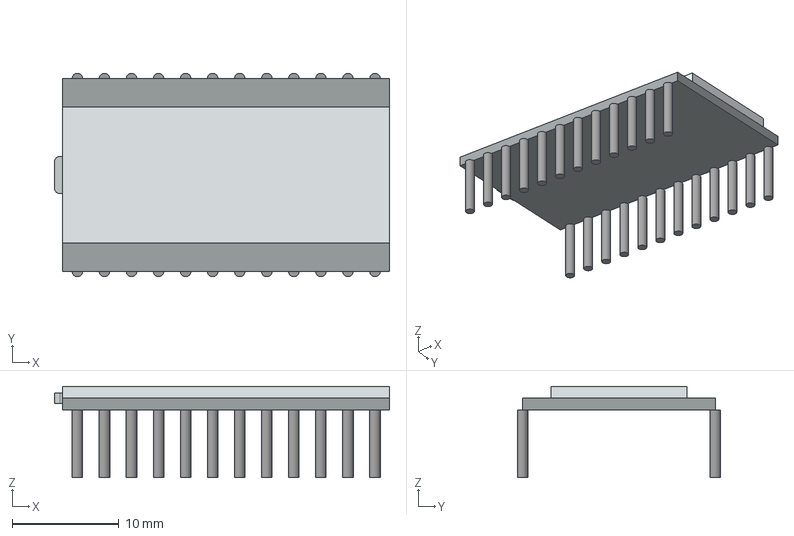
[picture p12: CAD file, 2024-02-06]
3_Mechanical/display_character_glass_lcd.FCStd
31.5 x 19.1 x 8.55 mm

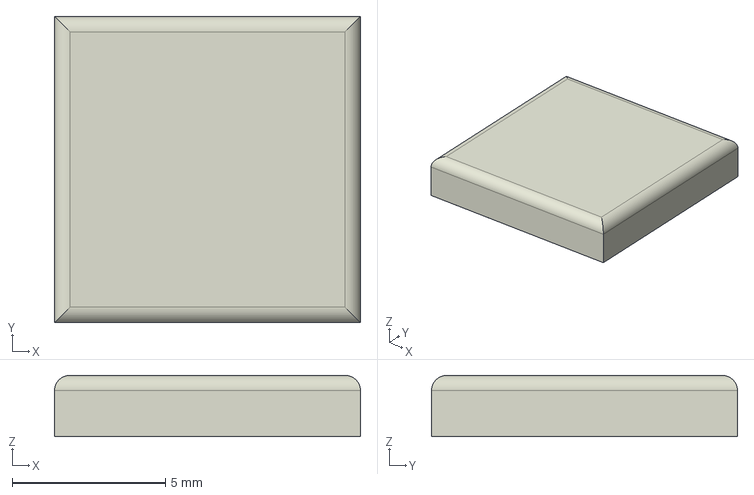
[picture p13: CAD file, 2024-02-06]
3_Mechanical/heatsink_ceramic_10x10mm.step
10.0 x 10.0 x 2.00 mm

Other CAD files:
3_Mechanical/LCD-S301C31TF.step
3_Mechanical/heatsink_ceramic_10x10mm.FCStd

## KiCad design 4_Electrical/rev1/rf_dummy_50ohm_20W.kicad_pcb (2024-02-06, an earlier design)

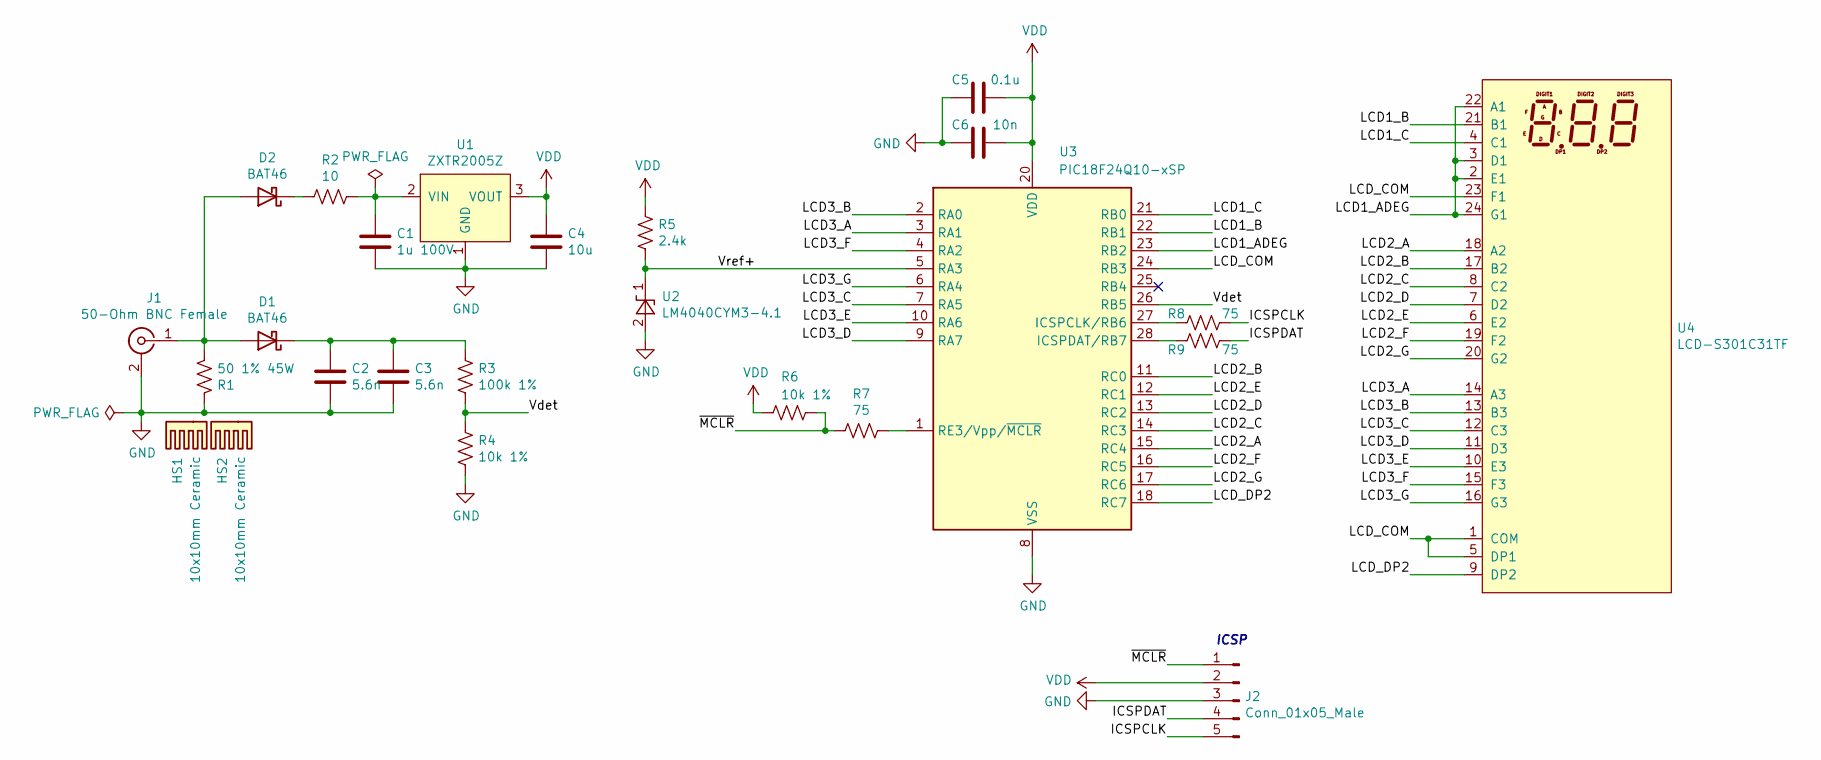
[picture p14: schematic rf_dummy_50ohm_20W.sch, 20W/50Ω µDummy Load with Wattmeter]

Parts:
C1: 1u 100V; C_1206_3216Metric_Pad1.42x1.75mm_HandSolder
C2, C3: 5.6n; C_Disc_D5.1mm_W3.2mm_P5.00mm
C4: 10u; C_1206_3216Metric_Pad1.42x1.75mm_HandSolder
C5: 0.1u; C_1206_3216Metric_Pad1.42x1.75mm_HandSolder
C6: 10n; C_1206_3216Metric_Pad1.42x1.75mm_HandSolder
D1, D2: BAT46; D_DO-34_SOD68_P7.62mm_Horizontal
HS1, HS2: 10x10mm Ceramic; Heatsink_Ceramic_Flat_10x10mm
J1: 50-Ohm BNC Female; BNC_TEConnectivity_1478204_Vertical
J2: Conn_01x05_Male; PinHeader_1x05_P2.54mm_Vertical
R1: 50 1% 45W; TO-252-2_TabPin1
R2: 10; R_1206_3216Metric_Pad1.42x1.75mm_HandSolder
R3: 100k 1%; R_1206_3216Metric_Pad1.42x1.75mm_HandSolder
R4, R6: 10k 1%; R_1206_3216Metric_Pad1.42x1.75mm_HandSolder
R5: 2.4k; R_1206_3216Metric_Pad1.42x1.75mm_HandSolder
R7, R8, R9: 75; R_1206_3216Metric_Pad1.42x1.75mm_HandSolder
U1: ZXTR2005Z; SOT-89-3
U2: LM4040CYM3-4.1; SOT-23
U3: PIC18F24Q10-xSP; SSOP-28_5.3x10.2mm_P0.65mm
U4: LCD-S301C31TF

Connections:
/ICSPCLK: J2.5, R8.1
/ICSPDAT: J2.4, R9.1
/LCD1_ADEG: U3.23 (RB2), U4.2 (E1), U4.3 (D1), U4.22 (A1), U4.24 (G1)
/LCD1_B: U3.22 (RB1), U4.21 (B1)
/LCD1_C: U3.21 (RB0), U4.4 (C1)
/LCD2_A: U3.15 (RC4), U4.18 (A2)
/LCD2_B: U3.11 (RC0), U4.17 (B2)
/LCD2_C: U3.14 (RC3), U4.8 (C2)
/LCD2_D: U3.13 (RC2), U4.7 (D2)
/LCD2_E: U3.12 (RC1), U4.6 (E2)
/LCD2_F: U3.16 (RC5), U4.19 (F2)
/LCD2_G: U3.17 (RC6), U4.20 (G2)
/LCD3_A: U3.3 (RA1), U4.14 (A3)
/LCD3_B: U3.2 (RA0), U4.13 (B3)
/LCD3_C: U3.7 (RA5), U4.12 (C3)
/LCD3_D: U3.9 (RA7), U4.11 (D3)
/LCD3_E: U3.10 (RA6), U4.10 (E3)
/LCD3_F: U3.4 (RA2), U4.15 (F3)
/LCD3_G: U3.6 (RA4), U4.16 (G3)
/LCD_COM: U3.24 (RB3), U4.1 (COM), U4.5 (DP1), U4.23 (F1)
/LCD_DP2: U3.18 (RC7), U4.9 (DP2)
/Vdet: R3.2, R4.1, U3.26 (RB5)
/Vref+: R5.1, U2.1 (K), U3.5 (RA3)
/~MCLR: J2.1, R6.1, R7.2
GND: C1.2, C2.2, C3.2, C4.2, C5.2, C6.2, J1.2 (Ext), J2.3, R1.1, R4.2, U1.1 (GND), U2.2 (A), U3.8 (VSS), U3.19 (VSS)
unnamed: C1.1, R2.1, U1.2 (VIN)
unnamed: C2.1, C3.1, D1.1 (K), R3.1
unnamed: D1.2 (A), D2.2 (A), J1.1 (In), R1.2
unnamed: D2.1 (K), R2.2
unnamed: R7.1, U3.1 (RE3/Vpp/~MCLR~)
unnamed: R8.2, U3.27 (ICSPCLK/RB6)
unnamed: R9.2, U3.28 (ICSPDAT/RB7)
VDD: C4.1, C5.1, C6.1, J2.2, R5.2, R6.2, U1.3 (VOUT), U3.20 (VDD)

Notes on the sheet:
ICSP

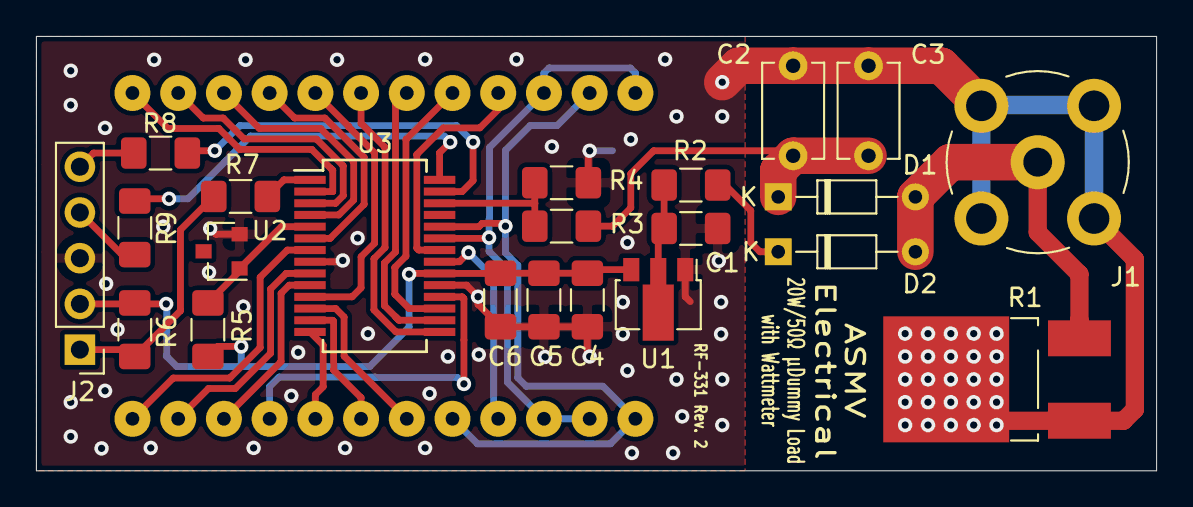
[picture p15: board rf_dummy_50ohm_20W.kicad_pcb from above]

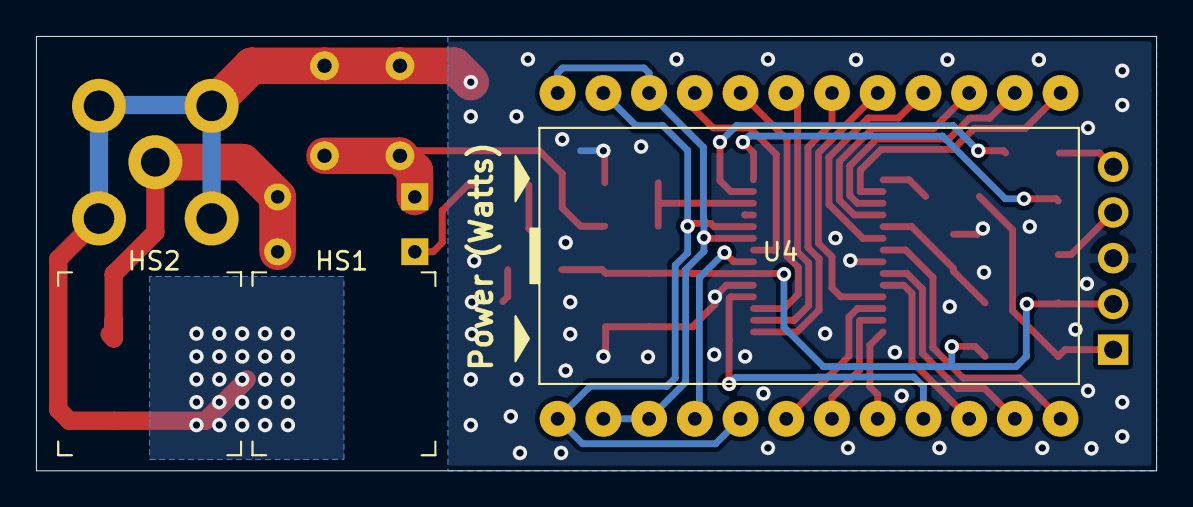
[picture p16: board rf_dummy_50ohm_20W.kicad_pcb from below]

Board: 2 copper layers, 62.2 x 24.1 mm, 25 parts (3 on the bottom side), 33 nets.

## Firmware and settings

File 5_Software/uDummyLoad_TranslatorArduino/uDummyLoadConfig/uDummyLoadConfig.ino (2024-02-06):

/*
 * uDummyLoadConfig.ino
 * ============================
 * ASMV Electrical
 * Last Updated: 04.18.2021
 * 
 * Writes configuration/calibration data to the uDummyLoad device. 
 * Requires three digital pins in addition to +5V and GND connections. 
 * Works with both 5V and 3.3V Arduino boards (change VDD accordingly.)
 * 
 * 
 * CONFIGURATION PROCEDURE
 * 
 * 1. Connect the uDummyLoad's 5-pin header to an Arduino board as
 *    shown below. Change the pin numbers in the `#define` statements
 *    to match the pins you use.
 * 
 *                                             +---------------------
 *                                             |
 *                                             |
 *                       FIVE PIN INTERFACE    |
 * +-----------------+                         |
 * |                 |=CLK <---------> PIN_CLK=|  Arduino
 * |                 |=DAT <---------> PIN_DAT=|  Microcontroller
 * |   uDummyLoad    |=GND <-------------- GND=|  Board
 * |                 |=VDD <-------------- +5V=|  (Uno, Nano, etc)
 * |                 |=RST*<---------- PIN_RST=| 
 * +-----------------+                         |
 *                                             |
 *   *Reset pin identified by square pad       |
 *                                             |
 *                                             +---------------------
 *                                             
 *                                             
 * WARNING: The uDummyLoad VDD and GND pins are not reverse-polarity
 * protected. Take care to connect them with the correct polarity.
 */
#define PIN_DAT 4
#define PIN_CLK 5
#define PIN_RST 6      
                                     
/*
 * 2. Confirm the serial settings below. Change the bitrate if needed. 
 *    If your Arduino board has multiple serial ports, replace `Serial` 
 *    with the port you are using. The serial console is used for 
 *    outputting status messages.
 */
#define SERIAL_BAUD 115200          // or 9600, 19200, 38400, etc
HardwareSerial *serial = &Serial;

/*
 * 3. Set the uDummyLoad configuration settings below as desired.
 *    
 *    Setting                    | Description
 *    -------------------------- | -----------------------------------------------------
 *    precision                  | Select 0.1W or 0.001W meter precision. The display 
 *                               |   scans between digits in the 0.001W mode.
 *    enableCalibration          | Enable calibration mode to bypass table lookup so that
 *                               |   calibration readings can be taken.
 *    enableDiodeComp            | Compensate the diode voltage drop in the peak voltage
 *                               |   reading by measuring the drop across a matched diode
 *                               |   (`true` enables the compensation; `false` disables)
 *    enableFactoryTest          | When true, the uDummyLoad runs the factory test on
 *                               |   startup, which consists of scanning through all LCD
 *                               |   digits among other operations.
 *    diodeOffsetMillivolts      | Fixed voltage to add to the peak voltage reading to
 *                               |   account for the difference in current flowing in
 *                               |   the compensation diode vs the peak detector diode
 *                               |   (fixed diode voltage drop when compensation disabled)
 *    displayUpdateMilliseconds  | Display update period in milliseconds 
 *    samplingPeriodMilliseconds | A/D sampling period in milliseconds
 *    table                      | Calibration table of up to 60 points for the wattmeter.
 *                               |   The uDummyLoad linearly interpolates between points
 *                               |   when looking up power readings.
 */
enum ePrecision {
    PRECISION_STANDARD = 0, // 0.1W
    PRECISION_EXTENDED = 1, // 0.001W
} precision = PRECISION_STANDARD;         // <= SELECT PRECISION
bool enableCalibration = false;           // <= ENABLE/DISABLE CALIBRATION MODE
bool enableDiodeComp = true;              // <= ENABLE/DISABLE DIODE COMPENSATION
bool enableFactoryTest = false;           // <= ENABLE/DISABLE FACTORY TEST MODE
uint16_t diodeOffsetMillivolts = 17;      // <= ENTER DIODE OFFSET (in mV)
uint16_t displayUpdateMilliseconds = 100; // <= ENTER DISPLAY UPDATE TIME (in msec)
uint8_t samplingPeriodMilliseconds = 20;  // <= ENTER SAMPLING PERIOD (in msec)
uint16_t table[61][2] = {
    // INSERT CALIBRATION DATA BELOW
    // Row format: (meter reading in milliwatts), (corrected value in milliwatts)
    //1234,       1234,

    // END OF TABLE
    0xFF,       0xFF,   // do not modify, marks end of table
};

/*
 * 4. Save and upload this sketch to your Arduino board using the 
 *    Arduino IDE.
 *    
 * 5. Open the Serial Monitor from the Arduino IDE and confirm that
 *    the correct uDummyLoad configuration options are displayed 
 *    on the screen. If any settings are incorrect, change the 
 *    options above and re-upload the sketch to your Arduino.
 *    
 * 6. Press enter on your keyboard or click the Send button in the 
 *    Serial Monitor to send configuration data to the uDummyLoad.
 *    
 * 7. Verify the configuration upload was successful: The serial
 *    output should display a "SUCCESS" message and the uDummyLoad
 *    should display 0.0W.
 *    
 * Troubleshooting: 
 * - If you receive garbled data over the serial port, ensure the baud
 *   rate setting in the Serial Monitor matches with step 2.
 * - If the uDummyLoad not flashes an "Ec" (error code) message or 
 *   this sketch outputs am error message, check your wiring and reset 
 *   your Arduino board to try again. Error code descriptions for
 *   the uDummyLoad follow:
 *   
 *   01  Timeout waiting for master (Arduino) to release DAT/CLK lines.
 *   02  Timeout waiting for master (Arduino) to send data.
 *   03  Receive buffer overflowed 255 bytes.
 *   04  Data header missing or malformed.
 *   05  Calibration table malformed.
 *   06  Calibration table not sorted in ascending order.

 *   
 * END CONFIGURATION PROCEDURE
 * DO NOT MODIFY CODE BELOW THIS LINE
 */

#define DATA_MAX_BYTES 255      // maximum number of bytes transmitted or received
#define TIMEOUT_MS 1000         // length of time after which most communication tasks fail with a timeout error
#define RESET_MS 100            // length of time to hold RST LOW to reset the uDummyLoad
#define TX_START_MS 200         // length of time to hold DAT/CLK LOW to initiate data transmission to uDummyLoad
#define RX_STOP_MS 100          // length of time without CLK activity signaling end of received data from uDummyLoad
#define TX_ACK_MS 100           // pulse duration for sending ACK to uDummyLoad
#define RX_ACK_MS 50            // expected ACK pulse duration when receiving from uDummyLoad
#define LINES_RELEASE_MS 10     // amount of time DAT/CLK must remain HIGH to be considered released

// configuration byte buffers
size_t bufLen = 0, rxLen = 0, tableLen;
uint8_t buf[DATA_MAX_BYTES] = {0};      // transmit buffer
uint8_t rxBuf[DATA_MAX_BYTES] = {0};    // read-back buffer

enum eError {
    ERROR_NONE = 0,
    ERROR_BUFFER_OVERFLOW = 1,
    ERROR_TIMEOUT = 2,
    ERROR_DATA_MISMATCH,
};

void setup() {
    char stringBuf[50];

    // compile configuration bytes
    PrepareConfigBytes(buf, &bufLen, &tableLen);

    serial->begin(SERIAL_BAUD);
    serial->println();
    serial->println(F("The following is to be transmitted to the uDummyLoad:"));
    serial->print(F("   Precision             : "));
    serial->println(precision == PRECISION_STANDARD ? F("standard (0.1W)") : F("extended (0.001W)"));
    serial->print(F("   Calibration Mode      : "));
    serial->println(enableCalibration ? F("enabled") : F("disabled"));
    serial->print(F("   Diode Compensation    : "));
    serial->println(enableDiodeComp ? F("enabled") : F("disabled"));
    serial->print(F("   Diode Offset Voltage  : "));
    serial->print(diodeOffsetMillivolts);
    serial->println(" mV");
    serial->print(F("   Display Update Period : "));
    serial->print(displayUpdateMilliseconds);
    serial->println(" ms");
    serial->print(F("   Sampling Period       : "));
    serial->print(samplingPeriodMilliseconds);
    serial->println(" ms");
    serial->println(F("   Calibration Table     : Meter Reading (mV) | Corrected Value (mV)"));
    serial->println(F("                           ------------------ | --------------------"));
    for (size_t i = 0; i < tableLen; ++i) {
        sprintf(stringBuf, "%18d | %20d", table[i][0], table[i][1]);
        Serial.print(F("                           "));
        Serial.println(stringBuf);
    } // for
    serial->print(F("                           ("));
    serial->print(tableLen);
    serial->println(F(" rows)"));
    serial->println(F("SEND ANY KEY TO PROCEED"));

    // wait for user input
    while(serial->available() == 0);

    serial->print(F("Transmitting: "));
    for (size_t i = 0; i < bufLen; ++i) {
        serial->print("0x");
        serial->print(buf[i], HEX);
        serial->print(" ");
    } // for
    serial->println();

    // transmit bytes
    enum eError error = WriteConfig(buf, bufLen, rxBuf, &rxLen);

    if (rxLen > 0) {
        serial->print(F("Read-Back   : "));
        for (size_t i = 0; i < rxLen; ++i) {
            serial->print("0x");
            serial->print(rxBuf[i], HEX);
            serial->print(" ");
        } // for
        serial->println(); 
    } // if

    switch (error) {
        case ERROR_NONE:
            serial->println(F("SUCCESS writing configuration data"));
            break;
            
        case ERROR_BUFFER_OVERFLOW:
            serial->println(F("ERROR: Receive buffer overflow"));
            break;
            
        case ERROR_TIMEOUT:
            serial->println(F("ERROR: Communication timeout; uDummyLoad failed to respond"));
            break;
            
        case ERROR_DATA_MISMATCH:
            serial->println(F("ERROR: Read-back data does not match transmitted data"));
            break;
    } // switch

    if (error != ERROR_NONE) {
        serial->println(F("Please check your wiring."));
    } // if
}

void loop() {
}

/*
 * Complile configuration settings into a byte array for transmission to the
 * uDummyLoad device.
 */
void PrepareConfigBytes(uint8_t *buf, size_t *bufLen, size_t *tableLen) {    
    *bufLen = 0;
    *tableLen = 0;
    
    // precision, diode comp, calibration mode, factory test
    buf[(*bufLen)++] =  (uint8_t)precision | 
                        (enableDiodeComp ? 2 : 0) | 
                        (enableCalibration ? 4 : 0) | 
                        (enableFactoryTest ? 8 : 0);
    // diode offset
    buf[(*bufLen)++] = (uint8_t)(diodeOffsetMillivolts & 0xFF);
    buf[(*bufLen)++] = (uint8_t)(diodeOffsetMillivolts >> 8);
    // display update time
    buf[(*bufLen)++] = (uint8_t)(displayUpdateMilliseconds & 0xFF);
    buf[(*bufLen)++] = (uint8_t)(displayUpdateMilliseconds >> 8);
    // sampling period
    buf[(*bufLen)++] = (uint8_t)(samplingPeriodMilliseconds & 0xFF);
    // calibration table
    uint8_t i;
    for (i = 0; table[i][0] != 0xFF && table[i][1] != 0xFF; ++i);   // determine table length
    buf[(*bufLen)++] = *tableLen = i;
    for (i = 0; i < *tableLen; ++i) {
        buf[(*bufLen)++] = (uint8_t)(table[i][0] & 0xFF);
        buf[(*bufLen)++] = (uint8_t)(table[i][0] >> 8);
        buf[(*bufLen)++] = (uint8_t)(table[i][1] & 0xFF);
        buf[(*bufLen)++] = (uint8_t)(table[i][1] >> 8);
    } // for
}

/*
 * Write configuration data to the uDummyLoad device and verify the correct data was 
 * received by load back.
 */
enum eError WriteConfig(uint8_t *txBuf, size_t len, uint8_t *rxBuf, size_t *rxLen) {    
    // Bootloader Initiation -------------------------------------------------------
    // reset the uDummyLoad device
    pinMode(PIN_DAT, OUTPUT);
    pinMode(PIN_CLK, OUTPUT);
    pinMode(PIN_RST, OUTPUT);
    digitalWrite(PIN_DAT, LOW);
    digitalWrite(PIN_CLK, LOW);
    digitalWrite(PIN_RST, LOW);
    delay(RESET_MS);
    // hold DAT/CLK LOW after reset to start the data transfer
    digitalWrite(PIN_RST, HIGH);
    delay(TX_START_MS);

    // uDummyLoad ACK -------------------------------------------------------------
    // wait for acknowledge signal from uDummyLoad (LOW on both DAT/CLK)
    pinMode(PIN_DAT, INPUT);
    pinMode(PIN_CLK, INPUT);
    if (!WaitForLines(LOW, RX_ACK_MS, TIMEOUT_MS)) {
        return ERROR_TIMEOUT;
    }
    // wait for uDummy load device to release the pins
    if (!WaitForLines(HIGH, LINES_RELEASE_MS, TIMEOUT_MS)) {
        return ERROR_TIMEOUT;
    }

    // Data Transmission ----------------------------------------------------------
    // clock out the data to the uDummyLoad
    pinMode(PIN_DAT, OUTPUT);
    pinMode(PIN_CLK, OUTPUT);
    WriteBytes(txBuf, len);

    // uDummyLoad ACK -------------------------------------------------------------
    // wait for acknowledge signal from uDummyLoad (LOW on both DAT/CLK)
    pinMode(PIN_DAT, INPUT);
    pinMode(PIN_CLK, INPUT);
    if (!WaitForLines(LOW, RX_ACK_MS, TIMEOUT_MS)) {
        return ERROR_TIMEOUT;
    }
    
    // Data Load-Back / Echo ------------------------------------------------------
    // receive bytes echoed by the uDummyLoad device
    enum eError rxError = ReceiveBytes(rxBuf, rxLen, DATA_MAX_BYTES, RX_STOP_MS, TIMEOUT_MS);
    if (rxError != ERROR_NONE) {
        return rxError;
    } // if
    // check that the echoed bytes are the same as those previously transmitted
    if (*rxLen != len || !BytesEqual(txBuf, rxBuf, len)) {
        return ERROR_DATA_MISMATCH;
    } // if

    // Master ACK -----------------------------------------------------------------
    // send acknowledge signal to uDummyLoad to commit the data to EEPROM
    pinMode(PIN_DAT, OUTPUT);
    pinMode(PIN_CLK, OUTPUT);
    digitalWrite(PIN_DAT, LOW);
    digitalWrite(PIN_CLK, LOW);
    delay(TX_ACK_MS);

    return ERROR_NONE;
}

/*
 * Transmit data bytes tp the uDummyLoad device. Software "bit banging" approach.
 * Least significant byte first; least significant bit first.
 * 
 * bytes - address of byte array to transmit
 * len - number of bytes to transmit from the array
 */
void WriteBytes(uint8_t *bytes, size_t len) {
    for (size_t k = 0; k < len; ++k) {
        for (uint8_t i = 0; i < 8; ++i) {
            digitalWrite(PIN_CLK, LOW);
            digitalWrite(PIN_DAT, bytes[k] & (1 << i) ? HIGH : LOW);
            delayMicroseconds(1000);
            digitalWrite(PIN_CLK, HIGH);
            delayMicroseconds(1000);
        } // for
    } // for
}

/*
 * Receive data bytes from the uDummyLoad device. Software "bit banging" approach.
 * Least significant byte first; least significant bit first.
 * 
 * buf - address of byte buffer in which to store received bytes
 * len - pointer to length variable where received byte count will be stored
 * maxLen - maximum length of the buffer (ERROR_BUFFER_OVERFLOW returned on overflow)
 * stopMs - amount of time required without activity on CLK line to signal STOP
 * timeoutMs - amount of time to wait to receive first byte before returning ERROR_TIMEOUT
 */
enum eError ReceiveBytes(uint8_t *buf, size_t *len, size_t maxLen, uint32_t stopMs, uint32_t timeoutMs) {
    enum eError error = ERROR_NONE;
    
    int8_t prevClk = -1, clk = -1, dat = -1;
    uint8_t byte = 0;       // bit accumulator
    uint8_t bitIndex = 0;   // index into bit accumulator
    uint8_t byteIndex = 0;  // index into byte buffer
    uint32_t now, rxMark;   // timing variables for detecting end of transmission (STOP signal)
    
    rxMark = millis();
    
    while (1) {
        now = millis();
        clk = digitalRead(PIN_CLK);
        dat = digitalRead(PIN_DAT);
        
        // store bits on rising clock edges (LSBs transmitted first)
        if (prevClk != -1 && prevClk == LOW && clk == HIGH) {
            byte |= dat << bitIndex;
            ++bitIndex;
        } // if
        
        // store byte once 8-bits received
        if (bitIndex >= 8) {
            // check for buffer overflow
            if (byteIndex >= maxLen) {
                error = ERROR_BUFFER_OVERFLOW;
                break;
            } // if

            // store byte
            buf[byteIndex] = byte;
            ++byteIndex;
            
            // clear the bit accumulator for next iteration
            byte = 0;                       
            bitIndex = 0;
        } // if
        
        // update receive time mark on clock edges
        if (prevClk != clk) {
            rxMark = now;
        } // if
        
        // stop receiving when clock level has not changed for 
        // the stop duration and we've received at least one byte
        if (byteIndex > 0 && now - rxMark > stopMs) {
            break;
        } // if
        
        // timeout if we haven't received any bytes
        if (byteIndex == 0 && now - rxMark > timeoutMs) {
            error = ERROR_TIMEOUT;
            break;
        } // if
        
        prevClk = clk;
    } // while
    
    *len = byteIndex;
    return error;
}

/*
 * Wait for the DAT/CLK lines to remain in the specified state for the specified
 * period. Configurable timeout.
 * 
 * state - the state of the lines to detect (HIGH or LOW)
 * period - the length of time the lines must remain at the specified state
 *     to constitute a positive detection
 * timeoutMs - maximum amount of time this function is allowed to hang waiting
 *     for a positive detection
 * 
 * Returns: 1 on positive detection; 0 on negative detection or timeout
 */
uint8_t WaitForLines(uint8_t state, uint32_t period, uint32_t timeoutMs) {
    uint8_t singleDetect = 0, pulseDetect = 0;
    uint32_t now, mark, singleMark;
    
    mark = singleMark = millis();
    
    while (1) {
        now = millis();
        
        // check timeout
        if (now - mark >= timeoutMs) {
            break;
        }
        
        // check for lines at the specified state at this single instant in time
        if (digitalRead(PIN_CLK) == state && digitalRead(PIN_DAT) == state) {
            if (!singleDetect) {
                singleDetect = 1;
                singleMark = now;
            } // if
        }
        else {
            singleDetect = 0;
        }
        
        // check for lines continuously at the specified state for the specified period
        if (singleDetect && now - singleMark >= period) {
            pulseDetect = 1;
            break;
        }
    } // while
    
    return pulseDetect;
}

/* 
 * Check equality of two byte arrays.
 * 
 * buf1 - address of first byte array
 * buf2 - address of second byte array
 * len - length of the arrays
 * 
 * Returns: true when all array elements are equal; false otherwise
 */
bool BytesEqual(uint8_t *buf1, uint8_t *buf2, size_t len) {
    for (size_t i = 0; i < len; ++i) {
        if (buf1[i] != buf2[i])
            return false;
    } // for

    return true;
}

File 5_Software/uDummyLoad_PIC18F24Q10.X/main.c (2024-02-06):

/*
 * 20W/50-Ohm micro-Dummy Load with Wattmeter
 * --------------------------------------
 * ASMV Electrical
 * Target: PIC18F24Q10
 * Last Updated: 04.12.2021
 * 
 * Periodically samples the divided envelope voltage, computes the power
 * dissipated by the 50-ohm load, and displays the result on the numeric
 * segmented LCD.
 * 
 * Abbreviations
 *  FVR = Fixed Voltage Reference
 *  A/D = Analog to digital
 *  DAC = Digital to Analog Converter
 *  LSb = Least-Significant bits (the unit of measure of A/D output codes)
 *  VDD = microcontroller positive supply voltage
 */

#include <stdint.h>
#include "mcc_generated_files/mcc.h"
#include <math.h>
#include "lcd.h"
#include "timing.h"
#include "pwrman.h"
#include "config.h"

// circular buffer length - sets the length of the peak voltage moving average
#define CIRCBUF_LENGTH 10

// digit scan time for 0.001W extended precision mode
#define DIGIT_SCAN_PERIOD_MS 1000

// default configuration data
// byte 0: number of configuration bytes following
// byte 1: precision(bit0), diodeCompEnable(bit1), calibrationEnable(bit2), factoryTestEnable(bit3)
// byte 2: diodeOffsetMv (LSB) 
// byte 3: diodeOffsetMv (MSB) 
// byte 4: displayPeriodMs (LSB)
// byte 5: displayPeriodMs (MSB)
// byte 6: samplingPeriodMs
// byte 7: tableLength (0 indicates table not loaded)
// additional 4*tableLength bytes for table data
__EEPROM_DATA(0x07, 0x02, 0x11, 0x00, 0x64, 0x00, 0x32, 0x00);

static void uDummyLoad_Initialize(void);
static void uDummyLoad_FactoryTest(void);
static uint32_t uDummyLoad_GetVpeakMillivolts(void);

// circular buffer implementation for averaging peak voltage readings
struct sCircBuf {
    uint8_t head;                       // index where next item is to be placed
    uint8_t runon;                      // index used to avoid run-on effect after startup
    uint32_t sum;                       // moving sum of buffer values
    uint32_t values[CIRCBUF_LENGTH];    // buffer values
};
// initialize a buffer
static void CircBuf_Init(struct sCircBuf *buf);
// place an item into the buffer
static void CircBuf_Store(struct sCircBuf *buf, uint32_t value);
// calculate the average of the buffered values
static uint32_t CircBuf_GetAvg(struct sCircBuf *buf);

void main(void) {
    uDummyLoad_Initialize();
    
    // run the factory test
    if (Config_IsFactoryTestEnabled())
        uDummyLoad_FactoryTest();
    
    struct sCircBuf vpeakBuf;
    uint32_t vpeakMillivolts, powerMilliwatts, powerDeciwatts;
    uint32_t now, sampleMark, displayMark, scanMark;
    uint8_t scanLower = 0;
    
    CircBuf_Init(&vpeakBuf);
    sampleMark = displayMark = scanMark = Timing_Milliseconds();
    
    while (1) {
        now = Timing_Milliseconds();
        
        // Peak Voltage Sampling -----------------------------------------------
        // periodically convert Vdivider and Vdiode, calculate the peak 
        // input voltage, and store the result into circular buffer
        if (now - sampleMark >= Config_GetSamplingPeriodMs()) {
            sampleMark = now;
            CircBuf_Store(&vpeakBuf, uDummyLoad_GetVpeakMillivolts());
        } // if
        
        // Display Update ------------------------------------------------------
        // periodically update the display with current power
        if (now - displayMark >= Config_GetDisplayPeriodMs()) {
            displayMark = now;
            
            // compute the average power absorbed by the load resistor as 
            //  P = Vpk^2/2*R
            // where 
            //  Vpk = averaged peak input voltage
            //  R = 50Ohms is the load resistance
            // The maximum error in the fixed-point computation is 2mW as 
            // determined by exhaustive numerical analysis.
            vpeakMillivolts = CircBuf_GetAvg(&vpeakBuf);
            powerMilliwatts = vpeakMillivolts * vpeakMillivolts / 100000;
            
            // apply calibration if we're not in calibration mode
            if (!Config_IsCalibrationEnabled())
                powerMilliwatts = Config_TableLookup((uint16_t)powerMilliwatts);
            
            powerDeciwatts = powerMilliwatts / 100; // integer division rounds down
            if (powerMilliwatts % 100 >= 50)
                // round up if remainder greater than or equal to 0.5dW
                ++powerDeciwatts;
            
            // display power reading as appropriate
            switch (Config_GetPrecision()) {
                // 0.1W precision
                case CONFIG_PRECISION_STANDARD:
                    LCD_Print((uint16_t)powerDeciwatts, 1);
                    break;
                
                // 0.001W precision
                case CONFIG_PRECISION_EXTENDED:
                    if (scanLower)
                        LCD_Print((uint16_t)powerMilliwatts % 100, 0);
                    else
                        LCD_Print((uint16_t)powerMilliwatts / 100, 1);
                    break;
            } // switch
        } // if
        
        // Digit Scan Tracking (Extended Precision Mode) -----------------------
        // - periodically toggle the `scanLower` variable which controls
        //   the display of the lower two milliwatt digits
        // - used in extended precision mode (0.001W) only
        if (now - scanMark >= DIGIT_SCAN_PERIOD_MS) {
            scanMark = now;
            scanLower = !scanLower;
        } // if
    } // while
}
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

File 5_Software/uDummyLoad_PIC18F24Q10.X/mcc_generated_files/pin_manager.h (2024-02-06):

/**
  @Generated Pin Manager Header File

  @Company:
    Microchip Technology Inc.

  @File Name:
    pin_manager.h

  @Summary:
    This is the Pin Manager file generated using PIC10 / PIC12 / PIC16 / PIC18 MCUs

  @Description
    This header file provides APIs for driver for .
    Generation Information :
        Product Revision  :  PIC10 / PIC12 / PIC16 / PIC18 MCUs - 1.81.6
        Device            :  PIC18F24Q10
        Driver Version    :  2.11
    The generated drivers are tested against the following:
        Compiler          :  XC8 2.30 and above
        MPLAB 	          :  MPLAB X 5.40	
*/

/*
    (c) 2018 Microchip Technology Inc. and its subsidiaries. 
    
    Subject to your compliance with these terms, you may use Microchip software and any 
    derivatives exclusively with Microchip products. It is your responsibility to comply with third party 
    license terms applicable to your use of third party software (including open source software) that 
    may accompany Microchip software.
    
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
    IN NO EVENT WILL MICROCHIP BE LIABLE FOR ANY INDIRECT, SPECIAL, PUNITIVE, 
    INCIDENTAL OR CONSEQUENTIAL LOSS, DAMAGE, COST OR EXPENSE OF ANY KIND 
    WHATSOEVER RELATED TO THE SOFTWARE, HOWEVER CAUSED, EVEN IF MICROCHIP 
    HAS BEEN ADVISED OF THE POSSIBILITY OR THE DAMAGES ARE FORESEEABLE. TO 
    THE FULLEST EXTENT ALLOWED BY LAW, MICROCHIP'S TOTAL LIABILITY ON ALL 
    CLAIMS IN ANY WAY RELATED TO THIS SOFTWARE WILL NOT EXCEED THE AMOUNT 
    OF FEES, IF ANY, THAT YOU HAVE PAID DIRECTLY TO MICROCHIP FOR THIS 
    SOFTWARE.
*/

#ifndef PIN_MANAGER_H
#define PIN_MANAGER_H

/**
  Section: Included Files
*/

#include <xc.h>

#define INPUT   1
#define OUTPUT  0

#define HIGH    1
#define LOW     0

#define ANALOG      1
#define DIGITAL     0

#define PULL_UP_ENABLED      1
#define PULL_UP_DISABLED     0

// get/set LCD3_B aliases
#define LCD3_B_TRIS                 TRISAbits.TRISA0
#define LCD3_B_LAT                  LATAbits.LATA0
#define LCD3_B_PORT                 PORTAbits.RA0
#define LCD3_B_WPU                  WPUAbits.WPUA0
#define LCD3_B_OD                   ODCONAbits.ODCA0
#define LCD3_B_ANS                  ANSELAbits.ANSELA0
#define LCD3_B_SetHigh()            do { LATAbits.LATA0 = 1; } while(0)
#define LCD3_B_SetLow()             do { LATAbits.LATA0 = 0; } while(0)
#define LCD3_B_Toggle()             do { LATAbits.LATA0 = ~LATAbits.LATA0; } while(0)
#define LCD3_B_GetValue()           PORTAbits.RA0
#define LCD3_B_SetDigitalInput()    do { TRISAbits.TRISA0 = 1; } while(0)
#define LCD3_B_SetDigitalOutput()   do { TRISAbits.TRISA0 = 0; } while(0)
#define LCD3_B_SetPullup()          do { WPUAbits.WPUA0 = 1; } while(0)
#define LCD3_B_ResetPullup()        do { WPUAbits.WPUA0 = 0; } while(0)
#define LCD3_B_SetPushPull()        do { ODCONAbits.ODCA0 = 0; } while(0)
#define LCD3_B_SetOpenDrain()       do { ODCONAbits.ODCA0 = 1; } while(0)
#define LCD3_B_SetAnalogMode()      do { ANSELAbits.ANSELA0 = 1; } while(0)
#define LCD3_B_SetDigitalMode()     do { ANSELAbits.ANSELA0 = 0; } while(0)

// get/set LCD3_A aliases
#define LCD3_A_TRIS                 TRISAbits.TRISA1
#define LCD3_A_LAT                  LATAbits.LATA1
#define LCD3_A_PORT                 PORTAbits.RA1
#define LCD3_A_WPU                  WPUAbits.WPUA1
#define LCD3_A_OD                   ODCONAbits.ODCA1
#define LCD3_A_ANS                  ANSELAbits.ANSELA1
#define LCD3_A_SetHigh()            do { LATAbits.LATA1 = 1; } while(0)
#define LCD3_A_SetLow()             do { LATAbits.LATA1 = 0; } while(0)
#define LCD3_A_Toggle()             do { LATAbits.LATA1 = ~LATAbits.LATA1; } while(0)
#define LCD3_A_GetValue()           PORTAbits.RA1
#define LCD3_A_SetDigitalInput()    do { TRISAbits.TRISA1 = 1; } while(0)
#define LCD3_A_SetDigitalOutput()   do { TRISAbits.TRISA1 = 0; } while(0)
#define LCD3_A_SetPullup()          do { WPUAbits.WPUA1 = 1; } while(0)
#define LCD3_A_ResetPullup()        do { WPUAbits.WPUA1 = 0; } while(0)
#define LCD3_A_SetPushPull()        do { ODCONAbits.ODCA1 = 0; } while(0)
#define LCD3_A_SetOpenDrain()       do { ODCONAbits.ODCA1 = 1; } while(0)
#define LCD3_A_SetAnalogMode()      do { ANSELAbits.ANSELA1 = 1; } while(0)
#define LCD3_A_SetDigitalMode()     do { ANSELAbits.ANSELA1 = 0; } while(0)

// get/set LCD3_F aliases
#define LCD3_F_TRIS                 TRISAbits.TRISA2
#define LCD3_F_LAT                  LATAbits.LATA2
#define LCD3_F_PORT                 PORTAbits.RA2
#define LCD3_F_WPU                  WPUAbits.WPUA2
#define LCD3_F_OD                   ODCONAbits.ODCA2
#define LCD3_F_ANS                  ANSELAbits.ANSELA2
#define LCD3_F_SetHigh()            do { LATAbits.LATA2 = 1; } while(0)
#define LCD3_F_SetLow()             do { LATAbits.LATA2 = 0; } while(0)
#define LCD3_F_Toggle()             do { LATAbits.LATA2 = ~LATAbits.LATA2; } while(0)
#define LCD3_F_GetValue()           PORTAbits.RA2
#define LCD3_F_SetDigitalInput()    do { TRISAbits.TRISA2 = 1; } while(0)
#define LCD3_F_SetDigitalOutput()   do { TRISAbits.TRISA2 = 0; } while(0)
#define LCD3_F_SetPullup()          do { WPUAbits.WPUA2 = 1; } while(0)
#define LCD3_F_ResetPullup()        do { WPUAbits.WPUA2 = 0; } while(0)
#define LCD3_F_SetPushPull()        do { ODCONAbits.ODCA2 = 0; } while(0)
#define LCD3_F_SetOpenDrain()       do { ODCONAbits.ODCA2 = 1; } while(0)
#define LCD3_F_SetAnalogMode()      do { ANSELAbits.ANSELA2 = 1; } while(0)
#define LCD3_F_SetDigitalMode()     do { ANSELAbits.ANSELA2 = 0; } while(0)

// get/set RA3 procedures
#define RA3_SetHigh()            do { LATAbits.LATA3 = 1; } while(0)
#define RA3_SetLow()             do { LATAbits.LATA3 = 0; } while(0)
#define RA3_Toggle()             do { LATAbits.LATA3 = ~LATAbits.LATA3; } while(0)
#define RA3_GetValue()              PORTAbits.RA3
#define RA3_SetDigitalInput()    do { TRISAbits.TRISA3 = 1; } while(0)
#define RA3_SetDigitalOutput()   do { TRISAbits.TRISA3 = 0; } while(0)
#define RA3_SetPullup()             do { WPUAbits.WPUA3 = 1; } while(0)
#define RA3_ResetPullup()           do { WPUAbits.WPUA3 = 0; } while(0)
#define RA3_SetAnalogMode()         do { ANSELAbits.ANSELA3 = 1; } while(0)
#define RA3_SetDigitalMode()        do { ANSELAbits.ANSELA3 = 0; } while(0)
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
